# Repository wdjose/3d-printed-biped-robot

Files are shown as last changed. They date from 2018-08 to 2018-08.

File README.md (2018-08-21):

# 3D-Printed Biped Robot
This repository contains the 3D model and the source code for the 3D-printed biped robot presented in the conference: 

> [W. J. D. Jose and M. C. Ramos, "Development of a 3D-printed biped robot with distributed joint control," 2018 4th International Conference on Control, Automation and Robotics (ICCAR), Auckland, 2018, pp. 71-75.](https://ieeexplore.ieee.org/document/8384647/ "Development of a 3D-printed biped robot with distributed joint control")

The biped robot was designed from scratch: all mechanical, electronic, and control designs were built by the authors. 

Below are descriptions of the directories in the repository: 
1. 3D Model: This contains the SolidWorks parts and assemblies which was 3D-printed and laser cut. 
2. PCB Schematic and Layout: This contains EAGLE schematic and layout files for both the master and joint controllers. 
3. Joint Controller: This is the MPLAB X project used for motor control for the joint controller. 
4. Master Controller: This is the MPLAB X project used for motion control of the biped for the master controller. 

Additional details can be provided upon request. 

This project was developed at Electrical and Electronics Engineering Institute, University of the Philippines Diliman.

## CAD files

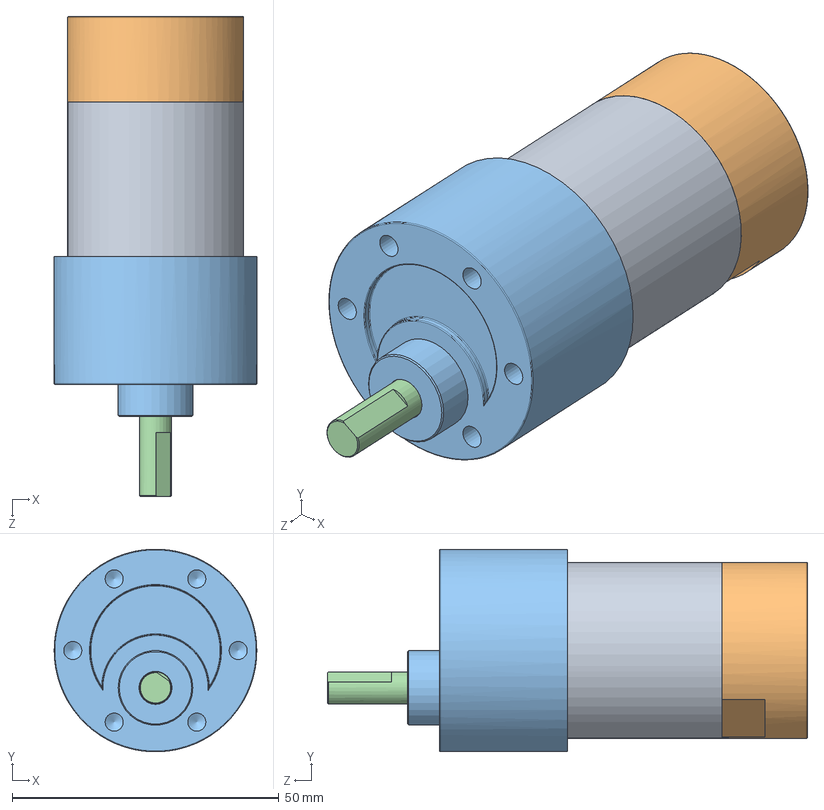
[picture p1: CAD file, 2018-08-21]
3D Model/Motor.SLDASM
38.0 x 38.0 x 90.0 mm
Motor Proper
Motor Encoder
Motor Gearbox
Motor Shaft

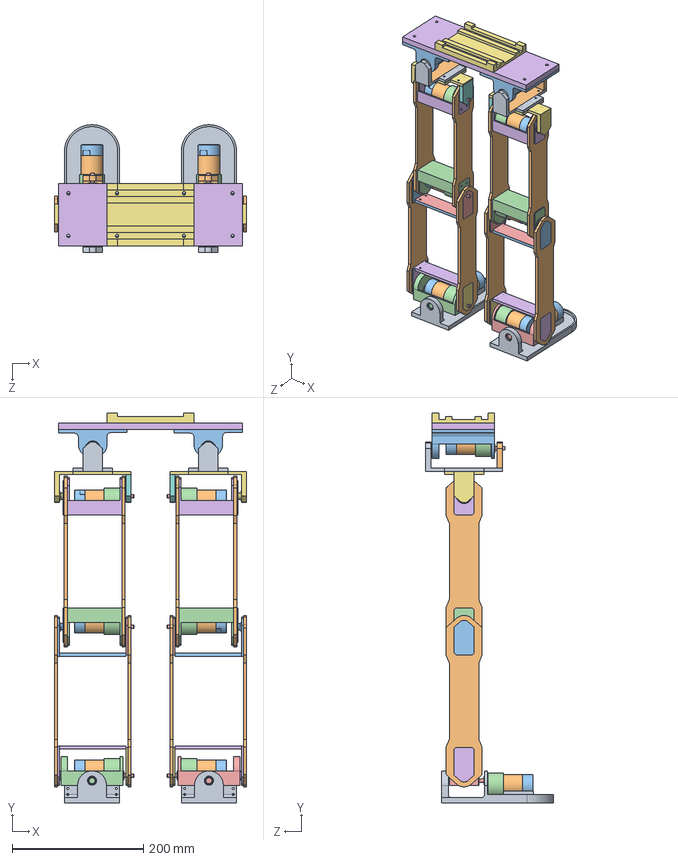
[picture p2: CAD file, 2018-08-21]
3D Model/Biped.SLDASM
293.0 x 593.9 x 194.5 mm
Foot x 2
Motor Proper x 10
Motor Encoder x 10
Motor Gearbox x 10
Motor Shaft x 10
Ankle Bearing x 2
Ankle DShaft x 2
Bearing Inner x 10
Bearing Outer x 10
Thigh and Shin x 8
Knee Bearing x 2
Knee x 2
Knee DShaft x 2
Hip A x 2
Hip Bearing A x 2
Hip DShaft A x 2
Hip Bearing B x 2
Hip DShaft B x 2
Hip B x 2
Ankle Left
Ankle Right
Torso Base
Torso Base Reinforcement

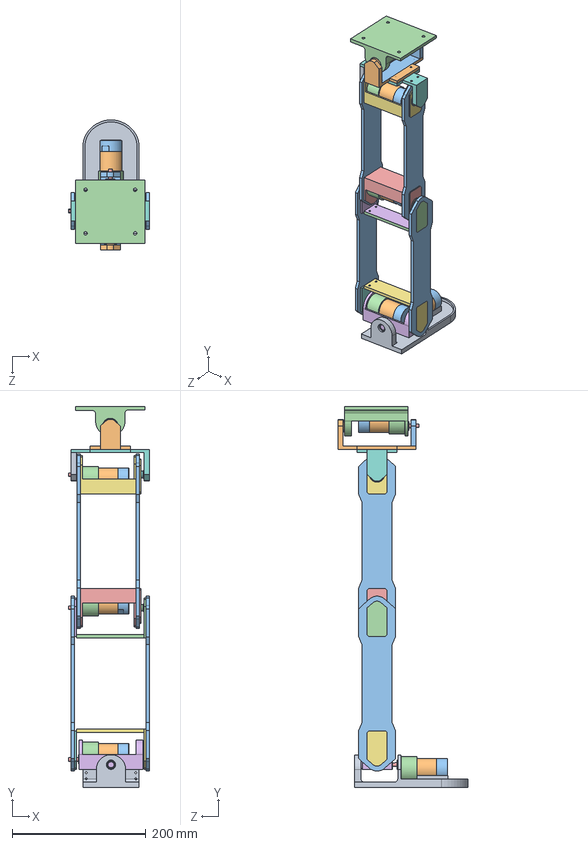
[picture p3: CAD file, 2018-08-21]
3D Model/Leg Right.SLDASM
121.0 x 568.9 x 194.5 mm
Foot
Motor Proper x 5
Motor Encoder x 5
Motor Gearbox x 5
Motor Shaft x 5
Ankle Right
Ankle Bearing
Ankle DShaft
Bearing Inner x 5
Bearing Outer x 5
Thigh and Shin x 4
Knee Bearing
Knee
Knee DShaft
Hip A
Hip Bearing A
Hip DShaft A
Hip Bearing B
Hip DShaft B
Hip B

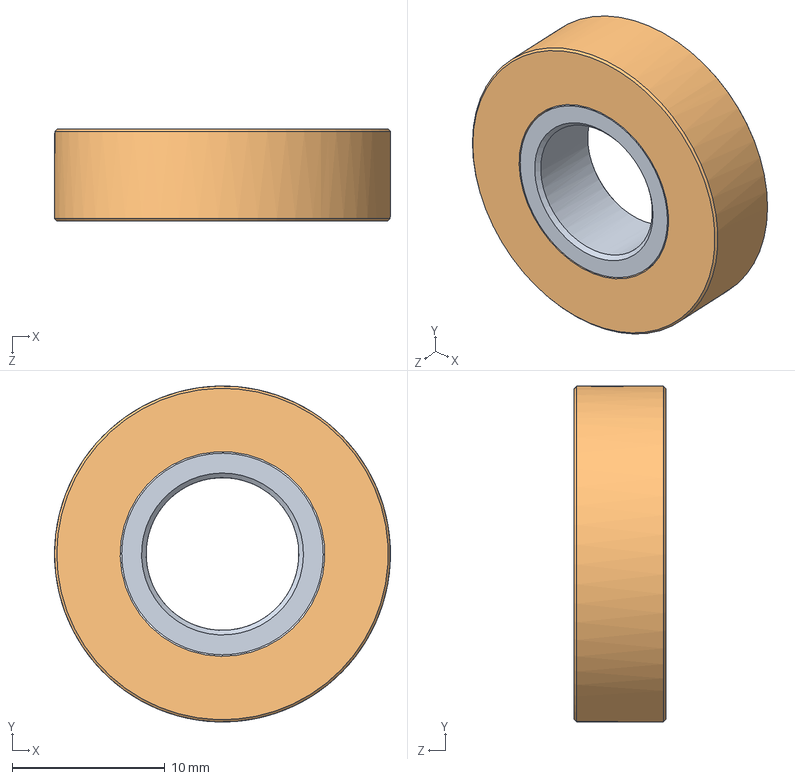
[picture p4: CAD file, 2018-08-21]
3D Model/Bearing.SLDASM
22.0 x 22.0 x 6.00 mm
Bearing Inner
Bearing Outer

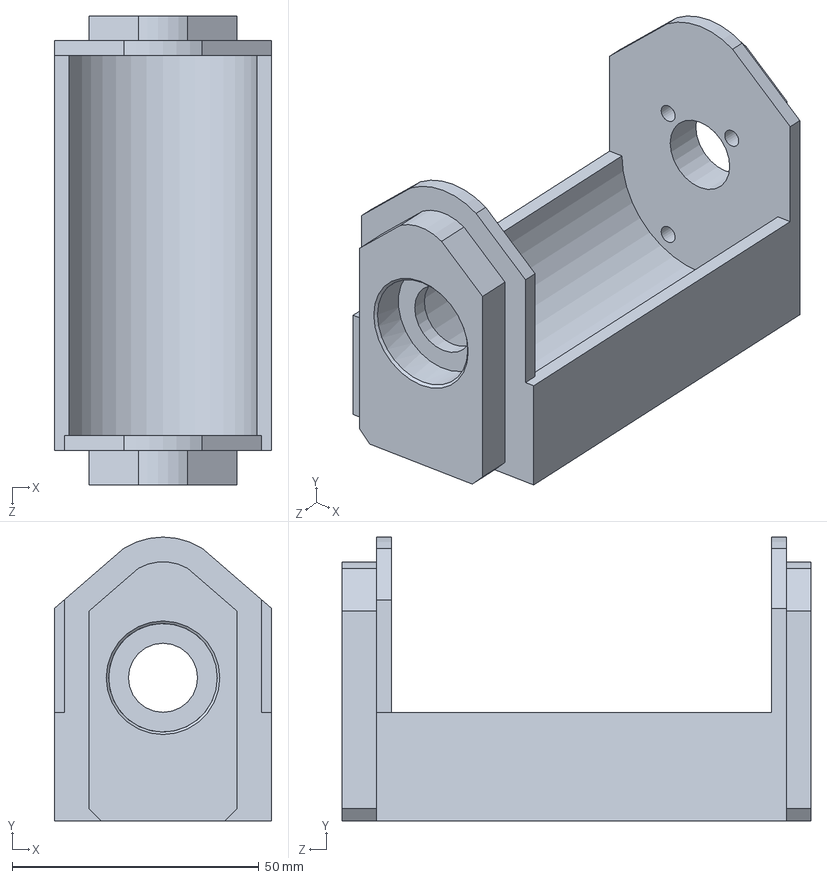
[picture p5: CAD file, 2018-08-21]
3D Model/Hip A.SLDPRT
44.0 x 57.5 x 95.0 mm

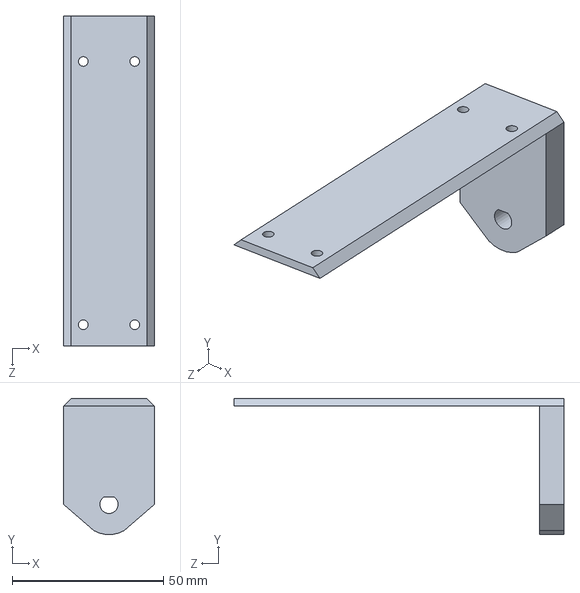
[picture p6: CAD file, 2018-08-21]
3D Model/Hip DShaft A.SLDPRT
30.0 x 44.9 x 109.0 mm

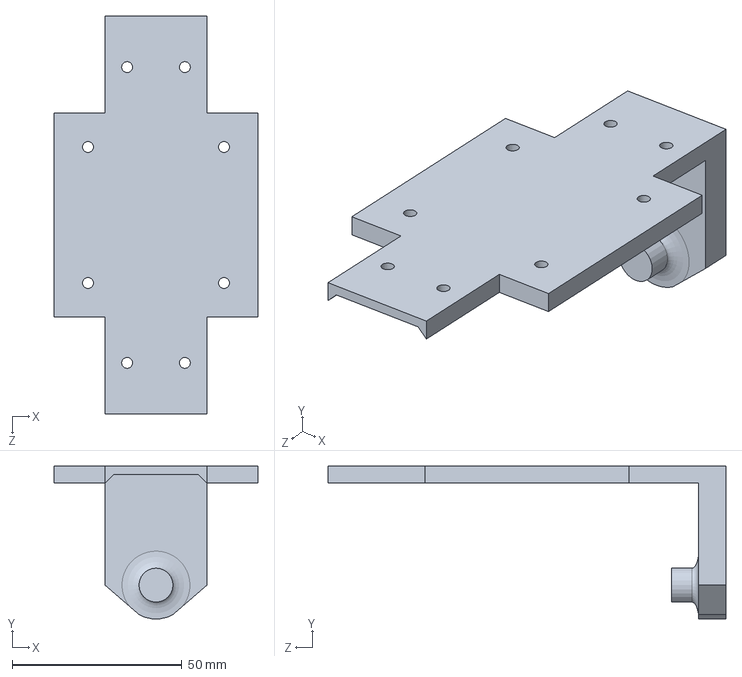
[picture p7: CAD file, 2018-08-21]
3D Model/Hip Bearing B.SLDPRT
60.0 x 44.9 x 117.0 mm

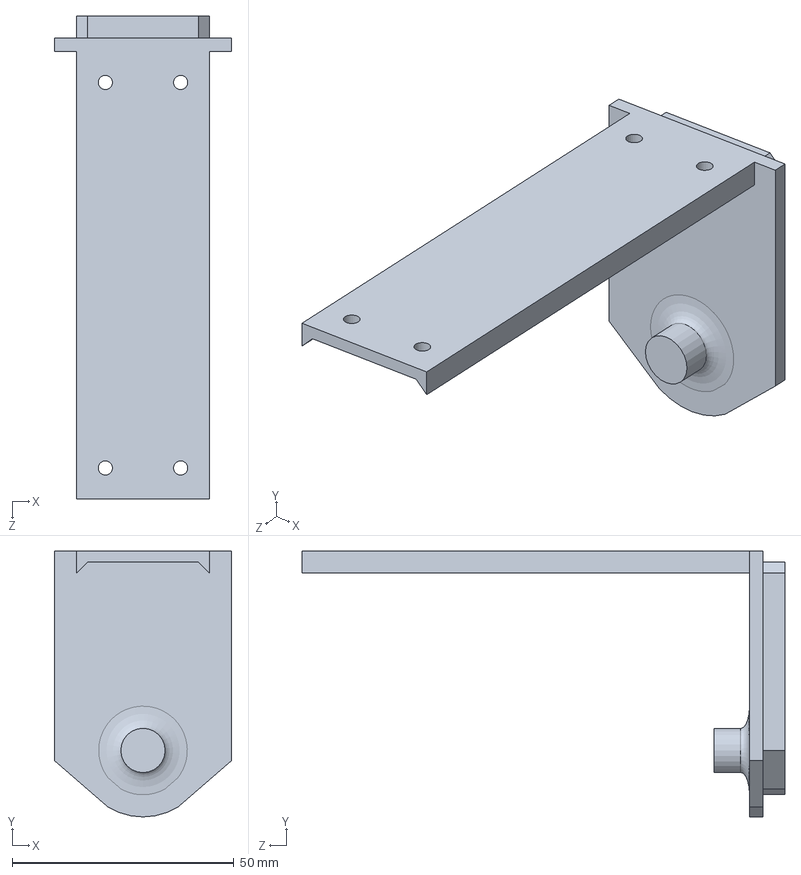
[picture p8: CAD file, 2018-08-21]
3D Model/Knee Bearing.SLDPRT
40.0 x 60.0 x 109.0 mm

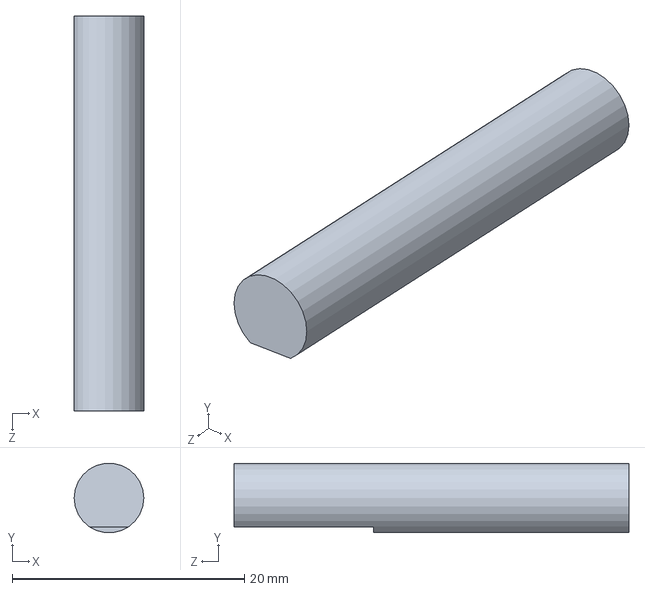
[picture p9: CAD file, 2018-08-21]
3D Model/Motor Shaft.SLDPRT
6.00 x 5.96 x 34.0 mm

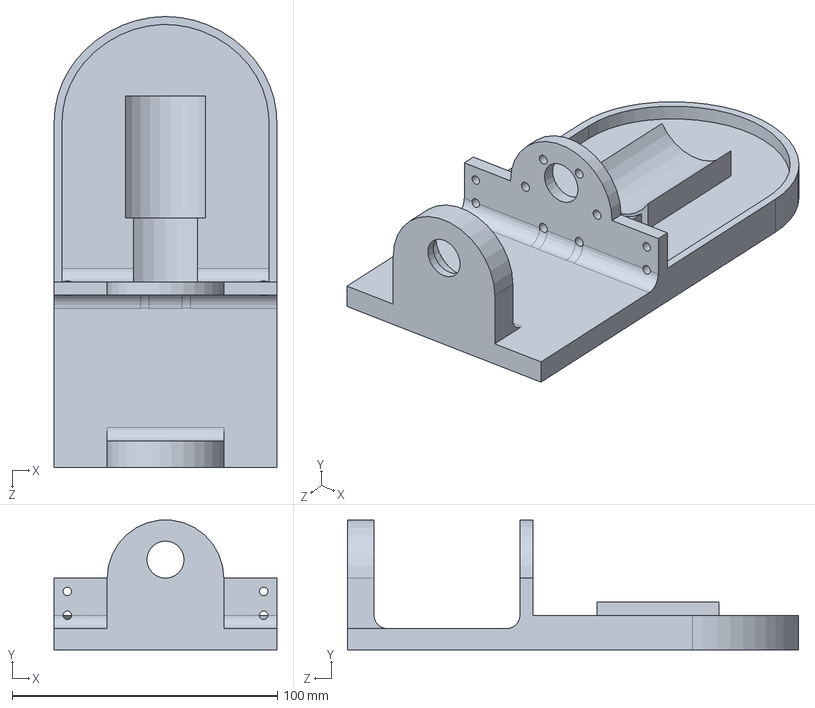
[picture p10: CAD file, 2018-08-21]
3D Model/Foot.SLDPRT
84.0 x 48.9 x 170.0 mm

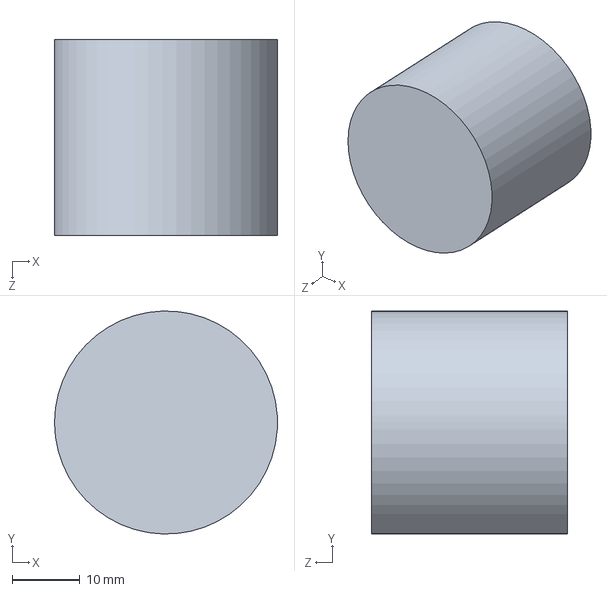
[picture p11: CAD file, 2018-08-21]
3D Model/Motor Proper.SLDPRT
33.0 x 33.0 x 29.0 mm

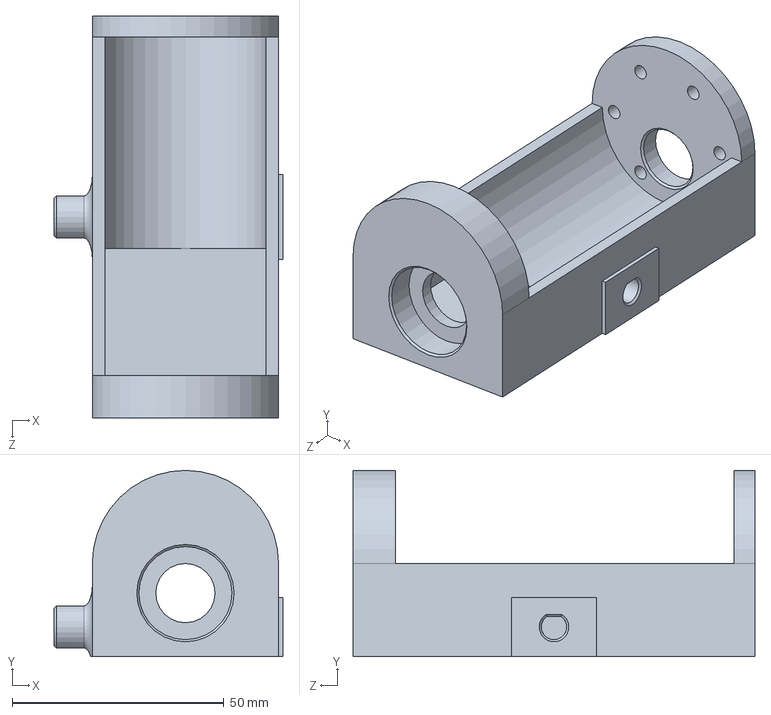
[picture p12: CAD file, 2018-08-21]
3D Model/Ankle Right.SLDPRT
54.0 x 44.0 x 95.0 mm

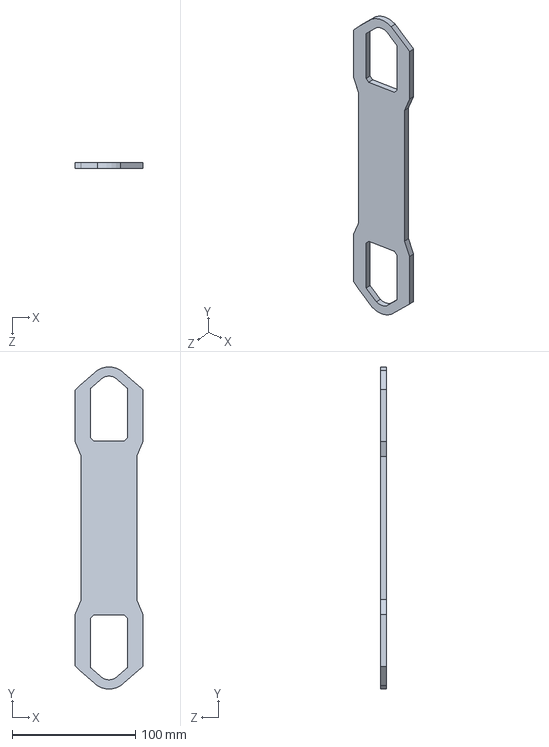
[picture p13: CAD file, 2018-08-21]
3D Model/Thigh and Shin.SLDPRT
55.0 x 261.0 x 5.00 mm

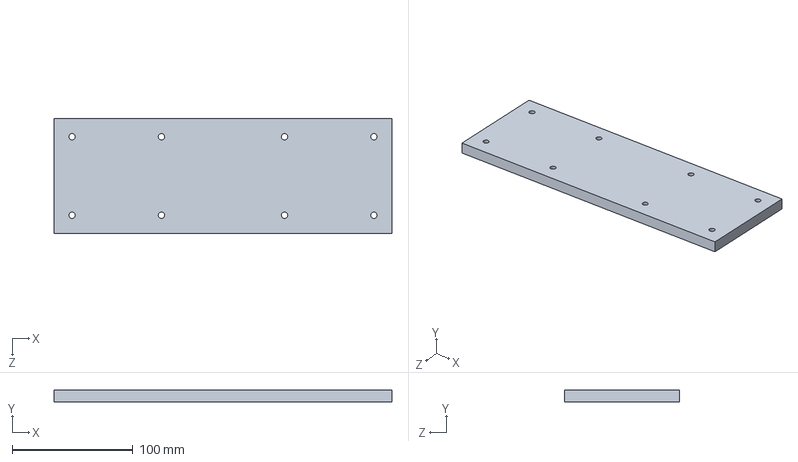
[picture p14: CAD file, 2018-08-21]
3D Model/Torso Base.SLDPRT
280.0 x 10.0 x 95.0 mm

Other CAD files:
3D Model/Leg Left.SLDASM
3D Model/Knee.SLDPRT
3D Model/Hip DShaft B.SLDPRT
3D Model/Bearing Outer.SLDPRT
3D Model/Ankle Bearing.SLDPRT
3D Model/Ankle DShaft.SLDPRT
3D Model/Ankle Left.SLDPRT
3D Model/Bearing Inner.SLDPRT
3D Model/Hip B.SLDPRT
3D Model/Hip Bearing A.SLDPRT
3D Model/Knee DShaft.SLDPRT
3D Model/Motor Encoder.SLDPRT
3D Model/Motor Gearbox.SLDPRT
3D Model/Torso Base Reinforcement.SLDPRT

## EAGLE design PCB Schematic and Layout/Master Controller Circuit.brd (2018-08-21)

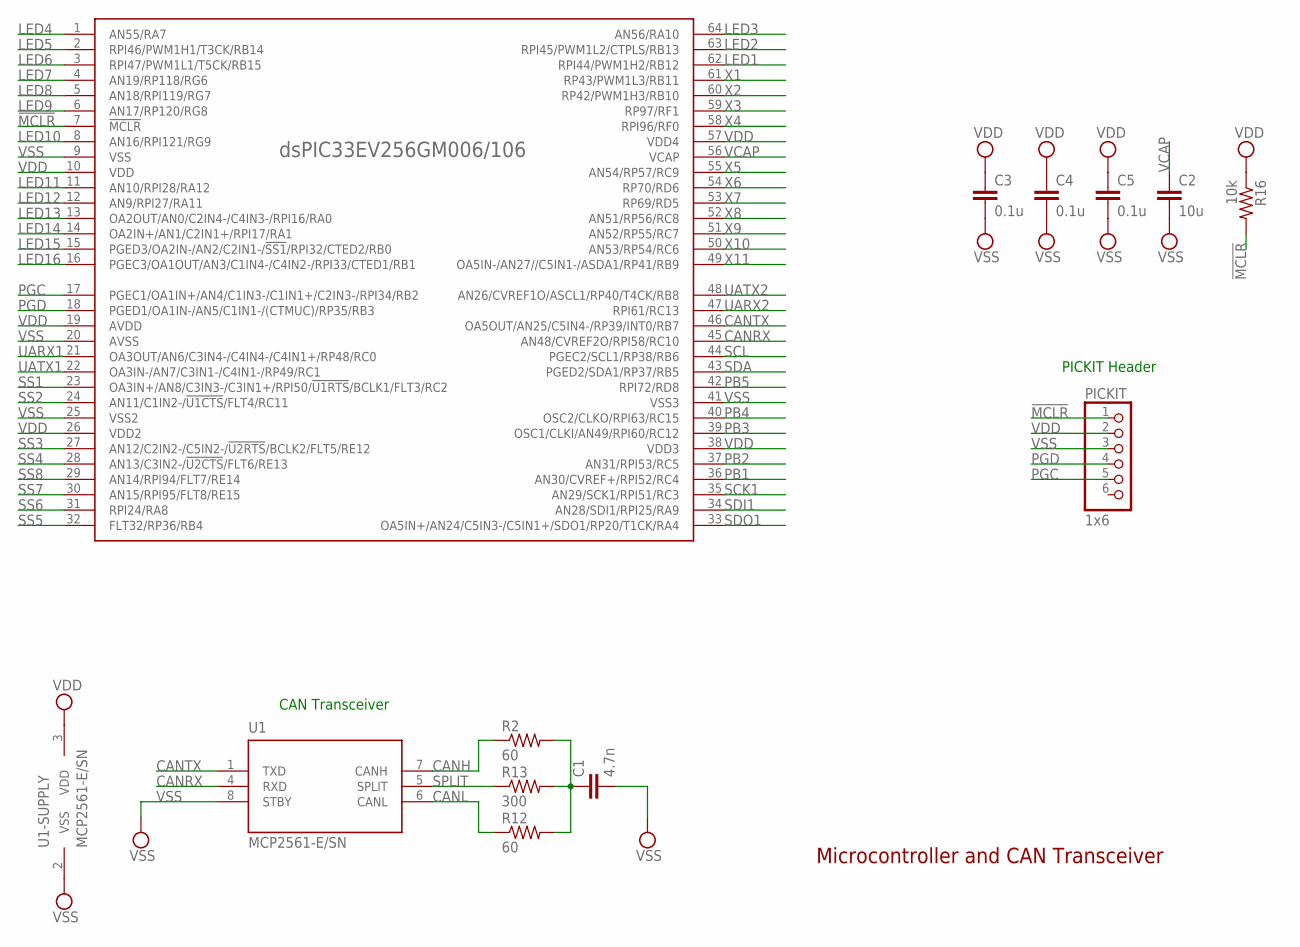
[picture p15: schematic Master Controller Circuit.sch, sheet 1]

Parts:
C1: 4.7n; C0805
C2: 10u; C0805
C3, C4, C5: 0.1u; C0805
PICKIT: 1x6; 1X06
R2, R12: 60; R0805
R13: 300; R0805
R16: 10k; R0805
U1: MCP2561-E/SN; SOIC-8
U$1: DSPIC33EV256GM106; TQFP64-10X10

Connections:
!MCLR: PICKIT.1, R16.2, U$1.7 (!MCLR); also elsewhere on the board
CANH: R2.1, U1.7 (CANH); also elsewhere on the board
CANL: R12.1, U1.6 (CANL); also elsewhere on the board
CANRX: U1.4 (RXD), U$1.45 (AN48/CVREF2O/RPI58/RC10)
CANTX: U1.1 (TXD), U$1.46 (OA5OUT/AN25/C5IN4-/RP39/INT0/RB7)
LED1: U$1.62 (RPI44/PWM1H2/RB12); also elsewhere on the board
LED2: U$1.63 (RPI45/PWM1L2/CTPLS/RB13); also elsewhere on the board
LED3: U$1.64 (AN56/RA10); also elsewhere on the board
LED4: U$1.1 (AN55/RA7); also elsewhere on the board
LED5: U$1.2 (RPI46/PWM1H1/T3CK/RB14); also elsewhere on the board
LED6: U$1.3 (RPI47/PWM1L1/T5CK/RB15); also elsewhere on the board
LED7: U$1.4 (AN19/RP118/RG6); also elsewhere on the board
LED8: U$1.5 (AN18/RPI119/RG7); also elsewhere on the board
LED9: U$1.6 (AN17/RP120/RG8); also elsewhere on the board
LED10: U$1.8 (AN16/RPI121/RG9); also elsewhere on the board
LED11: U$1.11 (AN10/RPI28/RA12); also elsewhere on the board
LED12: U$1.12 (AN9/RPI27/RA11); also elsewhere on the board
LED13: U$1.13 (OA2OUT/AN0/C2IN4-/C4IN3-/RPI16/RA0); also elsewhere on the board
LED14: U$1.14 (OA2IN+/AN1/C2IN1+/RPI17/RA1); also elsewhere on the board
LED15: U$1.15 (PGED3/OA2IN-/AN2/C2IN1-/!SS1!/RPI32/CTE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); also elsewhere on the board
LED16: U$1.16 (PGEC3/OA1OUT/AN3/C1IN4-/C4IN2-/RPI33/CT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); also elsewhere on the board
unnamed: C1.1, R2.2, R12.2, R13.2
PB1: U$1.36 (AN30/CVREF+/RPI52/RC4); also elsewhere on the board
PB2: U$1.37 (AN31/RPI53/RC5); also elsewhere on the board
PB3: U$1.39 (OSC1/CLKI/AN49/RPI60/RC12); also elsewhere on the board
PB4: U$1.40 (OSC2/CLKO/RPI63/RC15); also elsewhere on the board
PB5: U$1.42 (RPI72/RD8); also elsewhere on the board
PGC: PICKIT.5, U$1.17 (PGEC1/OA1IN+/AN4/C1IN3-/C1IN1+/C2IN3-/R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)
PGD: PICKIT.4, U$1.18 (PGED1/OA1IN-/AN5/C1IN1-/(CTMUC)/RP35/RB3)
SCK1: U$1.35 (AN29/SCK1/RPI51/RC3); also elsewhere on the board
SCL: U$1.44 (PGEC2/SCL1/RP38/RB6); also elsewhere on the board
SDA: U$1.43 (PGED2/SDA1/RP37/RB5); also elsewhere on the board
SDI1: U$1.34 (AN28/SDI1/RPI25/RA9); also elsewhere on the board
SDO1: U$1.33 (OA5IN+/AN24/C5IN3-/C5IN1+/SDO1/RP20/T1C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); also elsewhere on the board
SPLIT: R13.1, U1.5 (SPLIT)
SS1: U$1.23 (OA3IN+/AN8/C3IN3-/C3IN1+/RPI50/!U1RTS!/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); also elsewhere on the board
SS2: U$1.24 (AN11/C1IN2-/!U1CTS!/FLT4/RC11); also elsewhere on the board
SS3: U$1.27 (AN12/C2IN2-/C5IN2-/!U2RTS!/BCLK2/FLT5/R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); also elsewhere on the board
SS4: U$1.28 (AN13/C3IN2-/!U2CTS!/FLT6/RE13); also elsewhere on the board
SS5: U$1.32 (FLT32/RP36/RB4); also elsewhere on the board
SS6: U$1.31 (RPI24/RA8); also elsewhere on the board
SS7: U$1.30 (AN15/RPI95/FLT8/RE15); also elsewhere on the board
SS8: U$1.29 (AN14/RPI94/FLT7/RE14); also elsewhere on the board
UARX1: U$1.21 (OA3OUT/AN6/C3IN4-/C4IN4-/C4IN1+/RP48/RC0); also elsewhere on the board
UARX2: U$1.47 (RPI61/RC13); also elsewhere on the board
UATX1: U$1.22 (OA3IN-/AN7/C3IN1-/C4IN1-/RP49/RC1); also elsewhere on the board
UATX2: U$1.48 (AN26/CVREF1O/ASCL1/RP40/T4CK/RB8); also elsewhere on the board
VCAP: C2.1, U$1.56 (VCAP)
VDD: C3.1, C4.1, C5.1, PICKIT.2, R16.1, U1.3 (VDD), U$1.10 (VDD), U$1.19 (AVDD), U$1.26 (VDD2), U$1.38 (VDD3), U$1.57 (VDD4); also elsewhere on the board
VSS: C1.2, C2.2, C3.2, C4.2, C5.2, PICKIT.3, U1.2 (VSS), U1.8 (STBY), U$1.9 (VSS), U$1.20 (AVSS), U$1.25 (VSS2), U$1.41 (VSS3); also elsewhere on the board
X1: U$1.61 (RP43/PWM1L3/RB11); also elsewhere on the board
X2: U$1.60 (RP42/PWM1H3/RB10); also elsewhere on the board
X3: U$1.59 (RP97/RF1); also elsewhere on the board
X4: U$1.58 (RPI96/RF0); also elsewhere on the board
X5: U$1.55 (AN54/RP57/RC9); also elsewhere on the board
X6: U$1.54 (RP70/RD6); also elsewhere on the board
X7: U$1.53 (RP69/RD5); also elsewhere on the board
X8: U$1.52 (AN51/RP56/RC8); also elsewhere on the board
X9: U$1.51 (AN52/RP55/RC7); also elsewhere on the board
X10: U$1.50 (AN53/RP54/RC6); also elsewhere on the board
X11: U$1.49 (OA5IN-/AN27//C5IN1-/ASDA1/RP41/RB9); also elsewhere on the board

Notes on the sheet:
PICKIT Header
CAN Transceiver
Microcontroller and CAN Transceiver

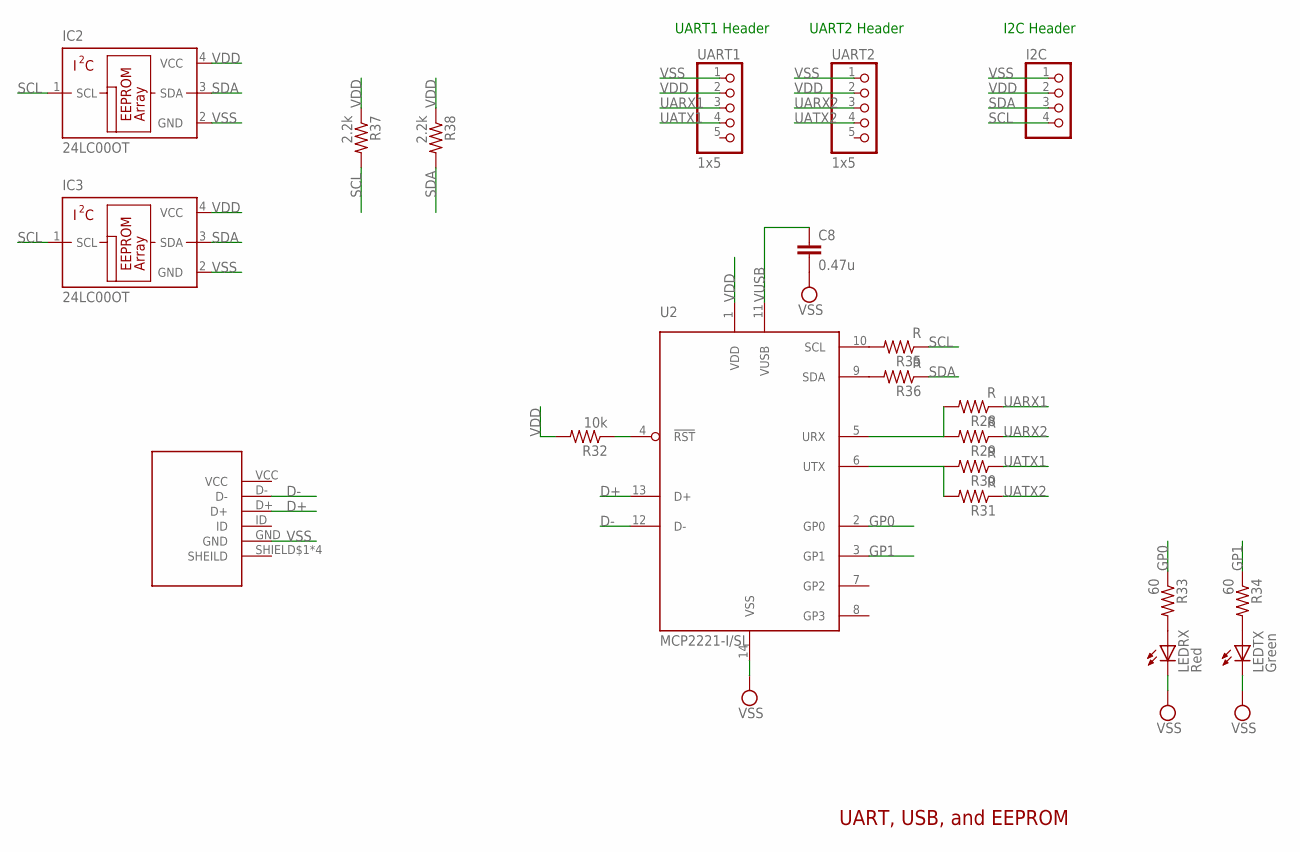
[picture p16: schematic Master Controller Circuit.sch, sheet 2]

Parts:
C8: 0.47u; C0805
I2C: PINHD-1X4; 1X04
IC2, IC3: 24LC00OT; SOT23-5L
J1: 10118193-0001LF
LEDRX: Red; CHIP-LED0805
LEDTX: Green; CHIP-LED0805
R28, R29, R30, R31, R35, R36: R; R0805
R32: 10k; R0805
R33, R34: 60; R0805
R37, R38: 2.2k; R0805
U2: MCP2221-I/SL; SOIC14
UART1, UART2: 1x5; 1X05

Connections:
D+: J1.D+, U2.13 (D+)
D-: J1.D-, U2.12 (D-)
GP0: R33.1, U2.2 (GP0)
GP1: R34.1, U2.3 (GP1)
unnamed: R28.2, R29.2, U2.5 (URX)
unnamed: R30.2, R31.2, U2.6 (UTX)
unnamed: R35.2, U2.10 (SCL)
unnamed: R36.2, U2.9 (SDA)
unnamed: R32.1, U2.4 (!RST)
unnamed: LEDRX.A, R33.2
unnamed: LEDTX.A, R34.2
SCL: I2C.4, IC2.1 (SCL), IC3.1 (SCL), R35.1, R37.2; also elsewhere on the board
SDA: I2C.3, IC2.3 (SDA), IC3.3 (SDA), R36.1, R38.2; also elsewhere on the board
UARX1: R28.1, UART1.3; also elsewhere on the board
UARX2: R29.1, UART2.3; also elsewhere on the board
UATX1: R30.1, UART1.4; also elsewhere on the board
UATX2: R31.1, UART2.4; also elsewhere on the board
VDD: I2C.2, IC2.4 (VCC), IC3.4 (VCC), R32.2, R37.1, R38.1, U2.1 (VDD), UART1.2, UART2.2; also elsewhere on the board
VSS: C8.2, I2C.1, IC2.2 (GND), IC3.2 (GND), J1.GND, LEDRX.C, LEDTX.C, U2.14 (VSS), UART1.1, UART2.1; also elsewhere on the board
VUSB: C8.1, U2.11 (VUSB)

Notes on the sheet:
UART, USB, and EEPROM
UART1 Header
UART2 Header
I2C Header

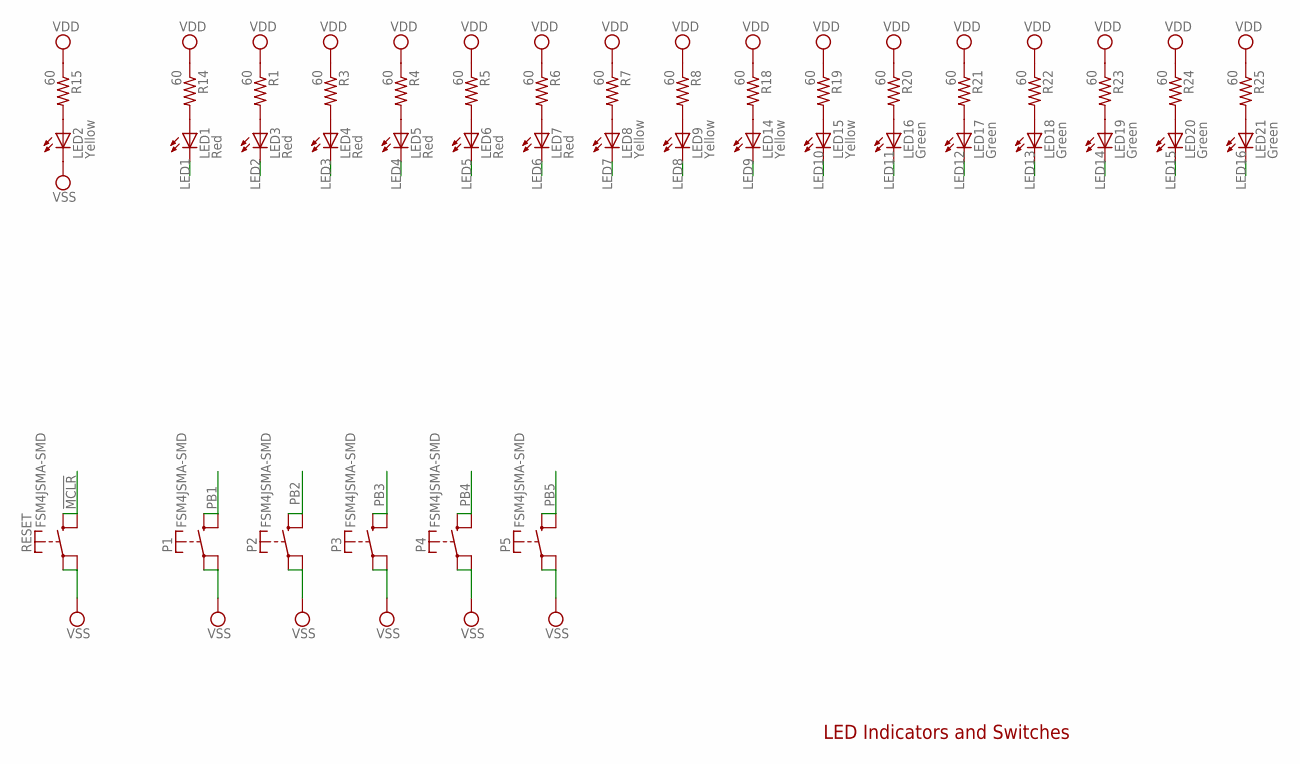
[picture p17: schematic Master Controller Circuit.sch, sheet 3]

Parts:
LED1, LED3, LED4, LED5, LED6, LED7: Red; CHIP-LED0805
LED2, LED8, LED9, LED14, LED15: Yellow; CHIP-LED0805
LED16, LED17, LED18, LED19, LED20, LED21: Green; CHIP-LED0805
P1, P2, P3, P4, P5: FSM4JSMA-SMD
R1, R3, R4, R5, R6, R7, R8, R14, R15, R18, R19, R20, R21, R22, R23, R24, R25: 60; R0805
RESET: FSM4JSMA-SMD

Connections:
!MCLR: RESET.P$3 (S), RESET.P$4 (S); also elsewhere on the board
LED1: LED1.C; also elsewhere on the board
LED2: LED3.C; also elsewhere on the board
LED3: LED4.C; also elsewhere on the board
LED4: LED5.C; also elsewhere on the board
LED5: LED6.C; also elsewhere on the board
LED6: LED7.C; also elsewhere on the board
LED7: LED8.C; also elsewhere on the board
LED8: LED9.C; also elsewhere on the board
LED9: LED14.C; also elsewhere on the board
LED10: LED15.C; also elsewhere on the board
LED11: LED16.C; also elsewhere on the board
LED12: LED17.C; also elsewhere on the board
LED13: LED18.C; also elsewhere on the board
LED14: LED19.C; also elsewhere on the board
LED15: LED20.C; also elsewhere on the board
LED16: LED21.C; also elsewhere on the board
unnamed: LED1.A, R14.2
unnamed: LED2.A, R15.2
unnamed: LED3.A, R1.2
unnamed: LED4.A, R3.2
unnamed: LED5.A, R4.2
unnamed: LED6.A, R5.2
unnamed: LED7.A, R6.2
unnamed: LED8.A, R7.2
unnamed: LED9.A, R8.2
unnamed: LED14.A, R18.2
unnamed: LED15.A, R19.2
unnamed: LED16.A, R20.2
unnamed: LED17.A, R21.2
unnamed: LED18.A, R22.2
unnamed: LED19.A, R23.2
unnamed: LED20.A, R24.2
unnamed: LED21.A, R25.2
PB1: P1.P$3 (S), P1.P$4 (S); also elsewhere on the board
PB2: P2.P$3 (S), P2.P$4 (S); also elsewhere on the board
PB3: P3.P$3 (S), P3.P$4 (S); also elsewhere on the board
PB4: P4.P$3 (S), P4.P$4 (S); also elsewhere on the board
PB5: P5.P$3 (S), P5.P$4 (S); also elsewhere on the board
VDD: R1.1, R3.1, R4.1, R5.1, R6.1, R7.1, R8.1, R14.1, R15.1, R18.1, R19.1, R20.1, R21.1, R22.1, R23.1, R24.1, R25.1; also elsewhere on the board
VSS: LED2.C, P1.P$1, P1.P$2, P2.P$1, P2.P$2, P3.P$1, P3.P$2, P4.P$1, P4.P$2, P5.P$1, P5.P$2, RESET.P$1, RESET.P$2; also elsewhere on the board

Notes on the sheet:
LED Indicators and Switches

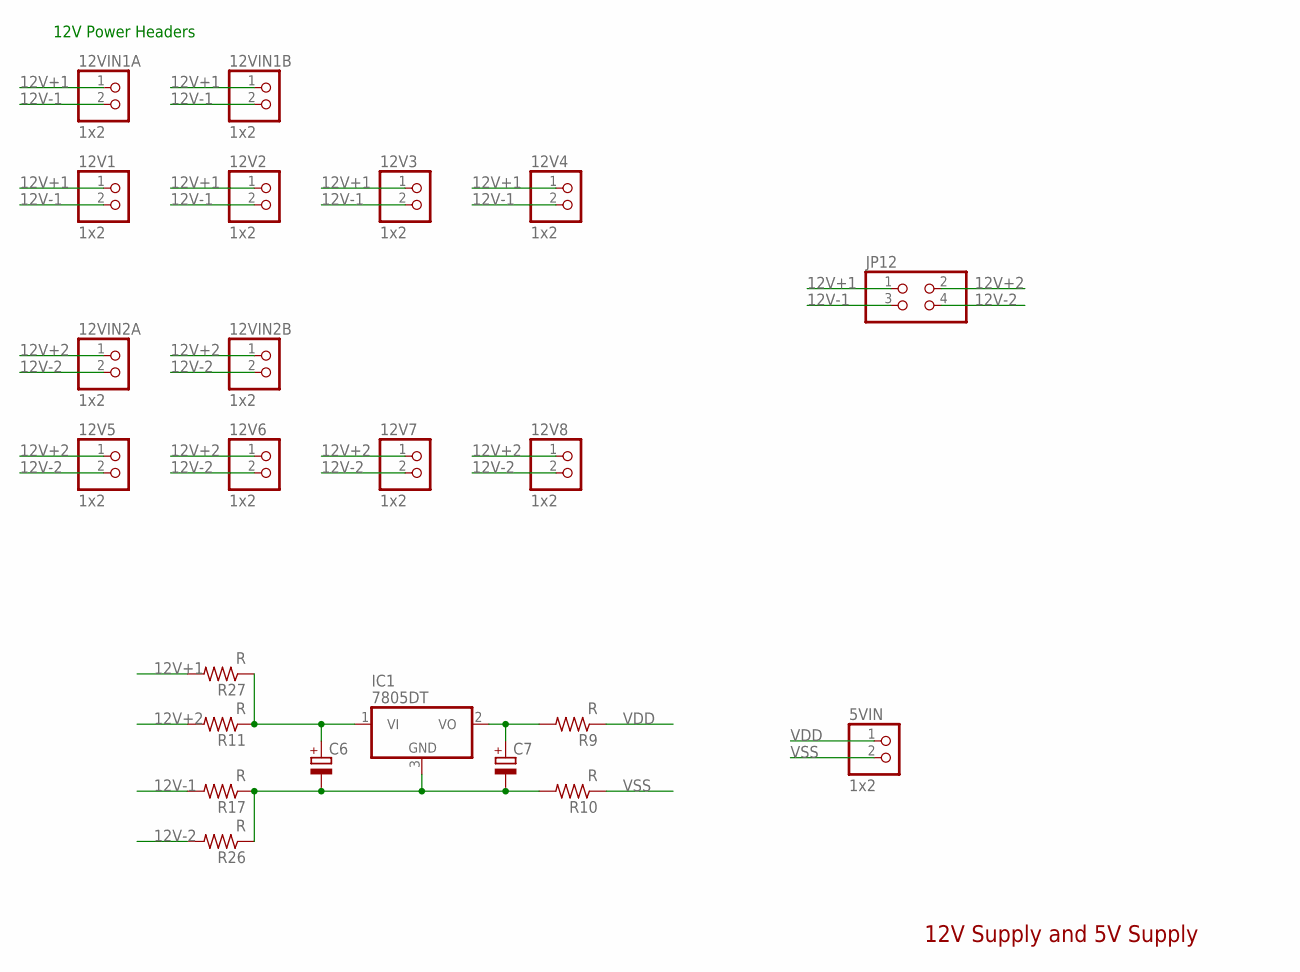
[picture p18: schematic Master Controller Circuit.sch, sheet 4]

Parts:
5VIN, 12V1, 12V2, 12V3, 12V4, 12V5, 12V6, 12V7, 12V8, 12VIN1A, 12VIN1B, 12VIN2A, 12VIN2B: 1x2; 1X02
C6, C7: CPOL-EU153CLV-0605; 153CLV-0605
IC1: 7805DT; TO252
JP12: PINHD-2X2; 2X02
R9, R10, R11, R17, R26, R27: R; R0805

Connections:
12V+1: 12V1.1, 12V2.1, 12V3.1, 12V4.1, 12VIN1A.1, 12VIN1B.1, JP12.1, R27.2
12V+2: 12V5.1, 12V6.1, 12V7.1, 12V8.1, 12VIN2A.1, 12VIN2B.1, JP12.2, R11.2
12V-1: 12V1.2, 12V2.2, 12V3.2, 12V4.2, 12VIN1A.2, 12VIN1B.2, JP12.3, R17.2
12V-2: 12V5.2, 12V6.2, 12V7.2, 12V8.2, 12VIN2A.2, 12VIN2B.2, JP12.4, R26.2
unnamed: C7.+, IC1.2 (VO), R9.2
unnamed: C6.-, C7.-, IC1.3 (GND), R10.2, R17.1, R26.1
unnamed: C6.+, IC1.1 (VI), R11.1, R27.1
VDD: 5VIN.1, R9.1; also elsewhere on the board
VSS: 5VIN.2, R10.1; also elsewhere on the board

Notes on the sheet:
12V Supply and 5V Supply
12V Power Headers

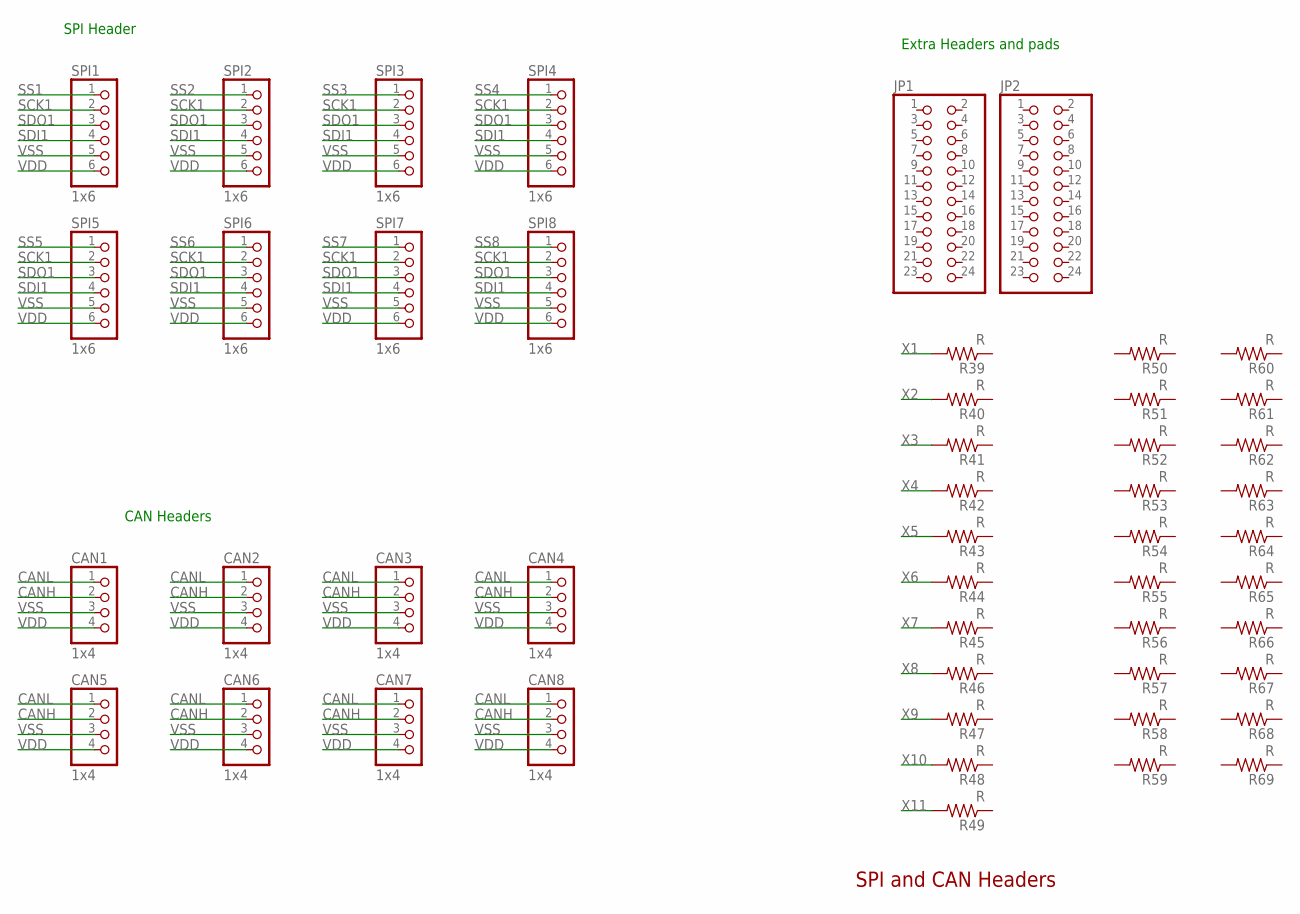
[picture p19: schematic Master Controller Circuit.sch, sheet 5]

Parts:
CAN1, CAN2, CAN3, CAN4, CAN5, CAN6, CAN7, CAN8: 1x4; 1X04
JP1, JP2: PINHD-2X12; 2X12
R39, R40, R41, R42, R43, R44, R45, R46, R47, R48, R49, R50, R51, R52, R53, R54, R55, R56, R57, R58, R59, R60, R61, R62, R63, R64, R65, R66, R67, R68, R69: R; R0603
SPI1, SPI2, SPI3, SPI4, SPI5, SPI6, SPI7, SPI8: 1x6; 1X06

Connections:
CANH: CAN1.2, CAN2.2, CAN3.2, CAN4.2, CAN5.2, CAN6.2, CAN7.2, CAN8.2; also elsewhere on the board
CANL: CAN1.1, CAN2.1, CAN3.1, CAN4.1, CAN5.1, CAN6.1, CAN7.1, CAN8.1; also elsewhere on the board
SCK1: SPI1.2, SPI2.2, SPI3.2, SPI4.2, SPI5.2, SPI6.2, SPI7.2, SPI8.2; also elsewhere on the board
SDI1: SPI1.4, SPI2.4, SPI3.4, SPI4.4, SPI5.4, SPI6.4, SPI7.4, SPI8.4; also elsewhere on the board
SDO1: SPI1.3, SPI2.3, SPI3.3, SPI4.3, SPI5.3, SPI6.3, SPI7.3, SPI8.3; also elsewhere on the board
SS1: SPI1.1; also elsewhere on the board
SS2: SPI2.1; also elsewhere on the board
SS3: SPI3.1; also elsewhere on the board
SS4: SPI4.1; also elsewhere on the board
SS5: SPI5.1; also elsewhere on the board
SS6: SPI6.1; also elsewhere on the board
SS7: SPI7.1; also elsewhere on the board
SS8: SPI8.1; also elsewhere on the board
VDD: CAN1.4, CAN2.4, CAN3.4, CAN4.4, CAN5.4, CAN6.4, CAN7.4, CAN8.4, SPI1.6, SPI2.6, SPI3.6, SPI4.6, SPI5.6, SPI6.6, SPI7.6, SPI8.6; also elsewhere on the board
VSS: CAN1.3, CAN2.3, CAN3.3, CAN4.3, CAN5.3, CAN6.3, CAN7.3, CAN8.3, SPI1.5, SPI2.5, SPI3.5, SPI4.5, SPI5.5, SPI6.5, SPI7.5, SPI8.5; also elsewhere on the board
X1: R39.2; also elsewhere on the board
X2: R40.2; also elsewhere on the board
X3: R41.2; also elsewhere on the board
X4: R42.2; also elsewhere on the board
X5: R43.2; also elsewhere on the board
X6: R44.2; also elsewhere on the board
X7: R45.2; also elsewhere on the board
X8: R46.2; also elsewhere on the board
X9: R47.2; also elsewhere on the board
X10: R48.2; also elsewhere on the board
X11: R49.2; also elsewhere on the board

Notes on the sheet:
SPI and CAN Headers
SPI Header
CAN Headers
Extra Headers and pads

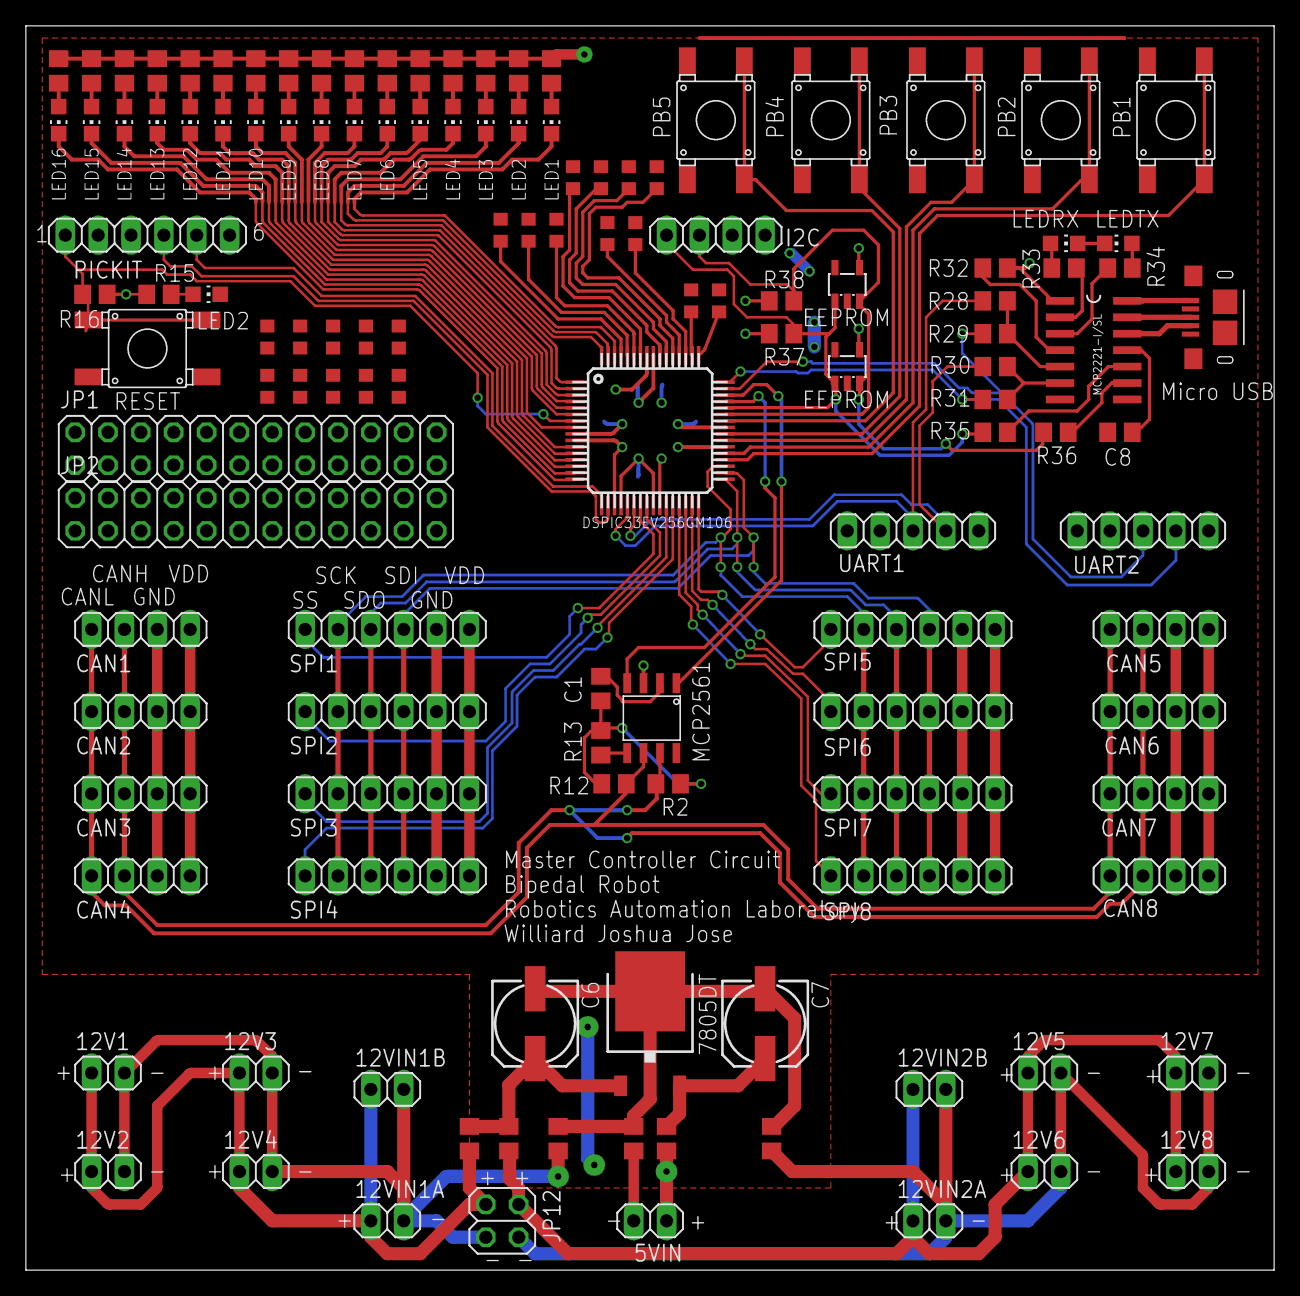
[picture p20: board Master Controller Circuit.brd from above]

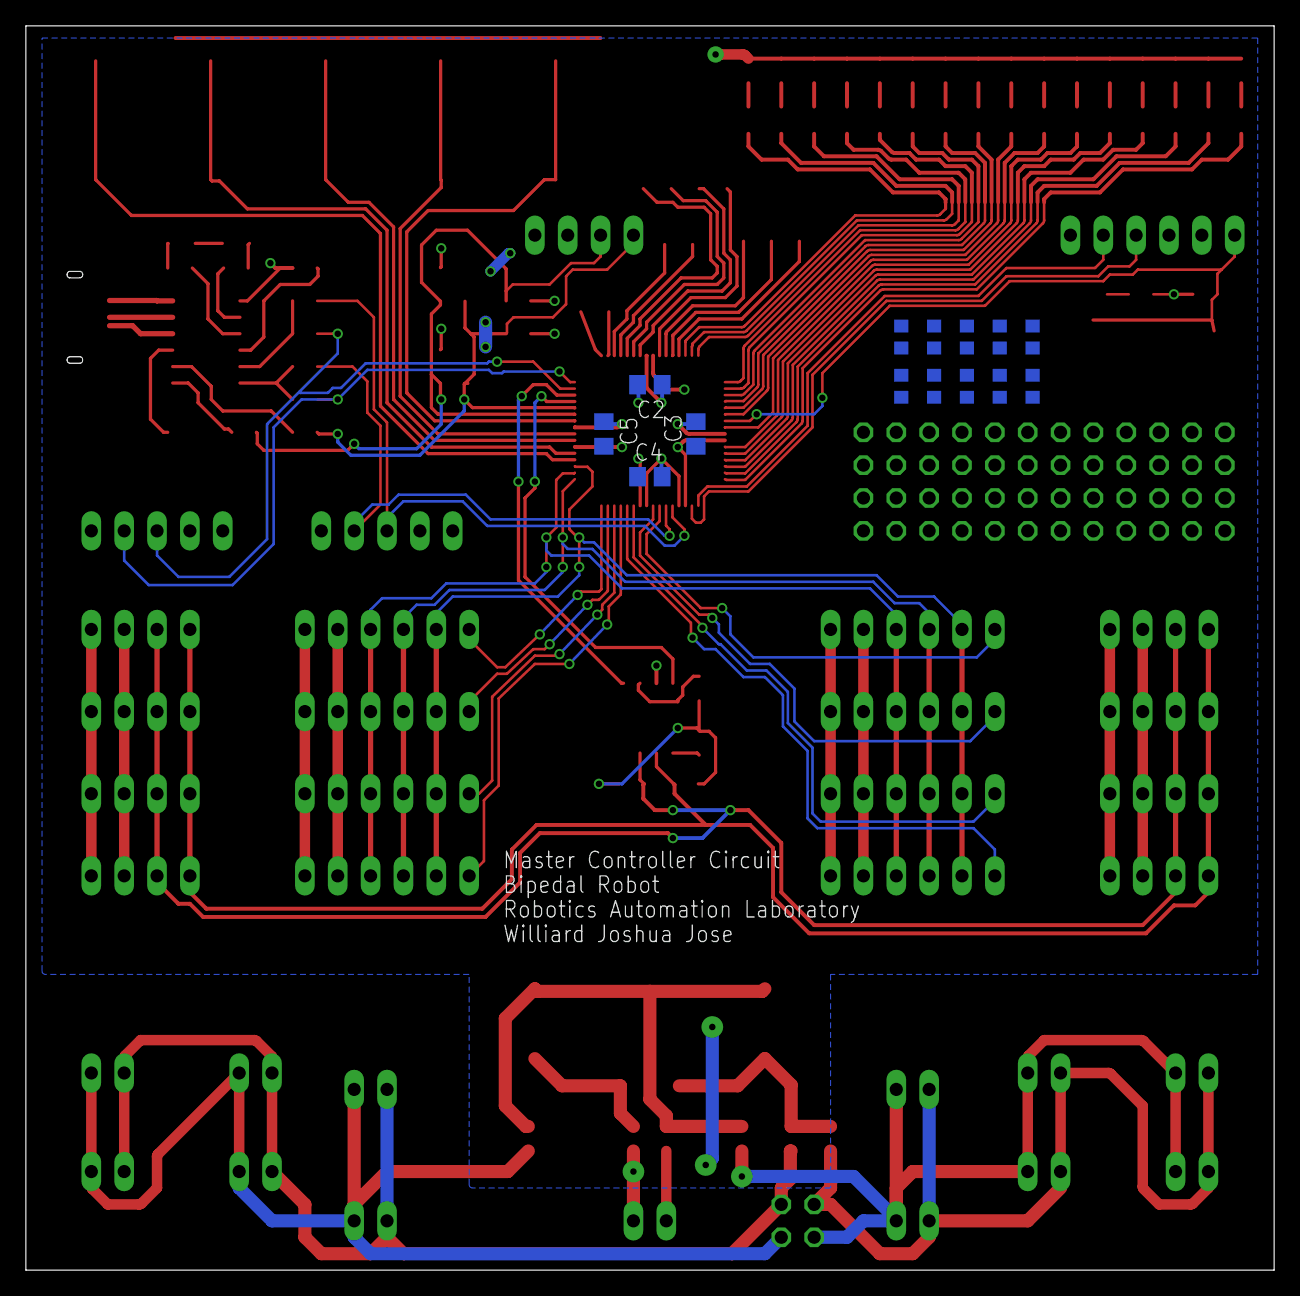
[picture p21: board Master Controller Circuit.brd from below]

Board: 2 copper layers, 96.5 x 96.2 mm, 145 parts (14 on the bottom side), 97 nets.

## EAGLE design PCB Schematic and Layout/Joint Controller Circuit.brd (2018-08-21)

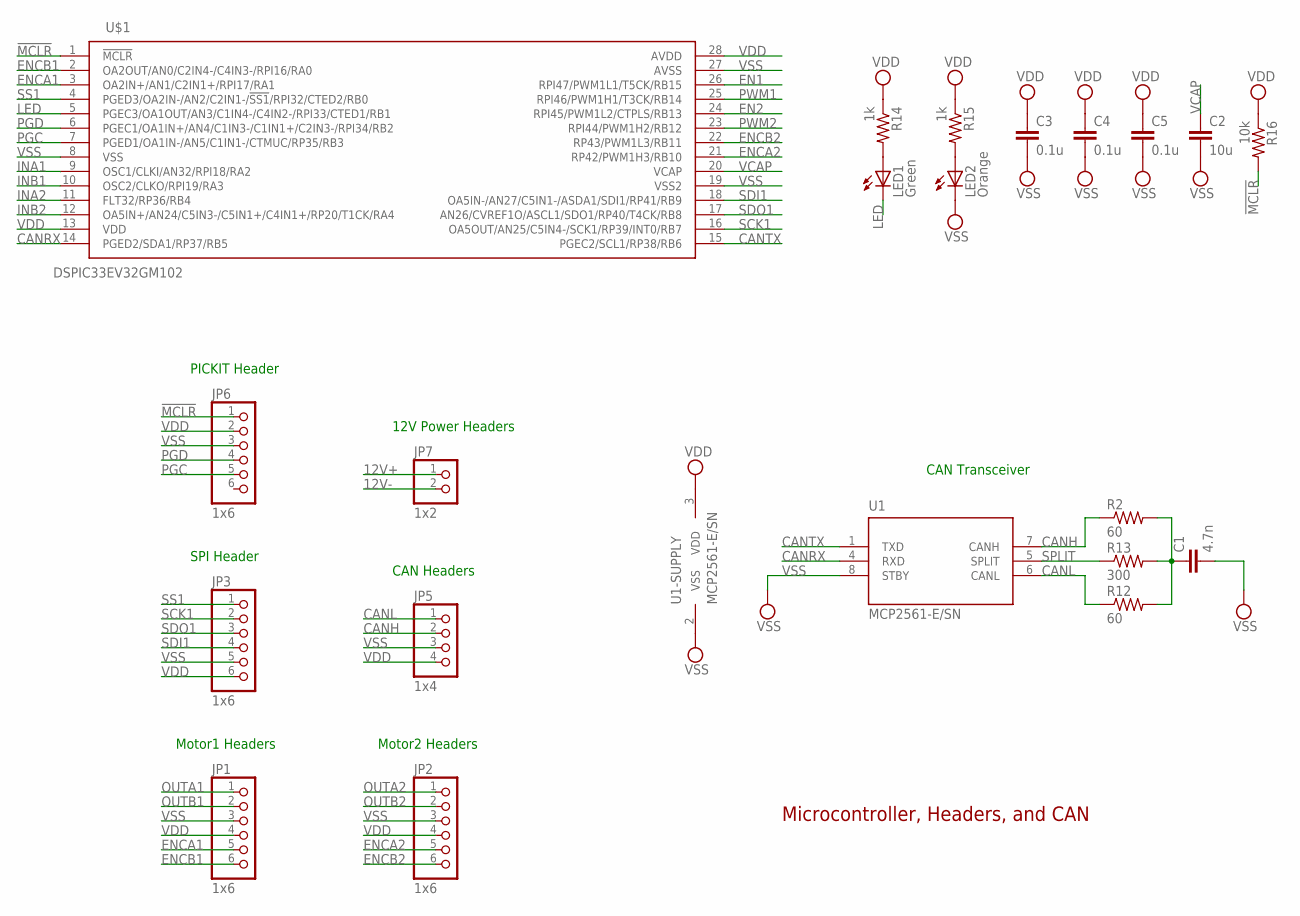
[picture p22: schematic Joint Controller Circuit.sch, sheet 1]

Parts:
C1: 4.7n; C0805
C2: 10u; C0805
C3, C4, C5: 0.1u; C0805
JP1, JP2, JP3, JP6: 1x6; 1X06
JP5: 1x4; 1X04
JP7: 1x2; 1X02
LED1: Green; CHIP-LED0805
LED2: Orange; CHIP-LED0805
R2, R12: 60; R0805
R13: 300; R0805
R14, R15: 1k; R0805
R16: 10k; R0805
U1: MCP2561-E/SN; SOIC-8
U$1: DSPIC33EV32GM102; SOIC28

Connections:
12V+: JP7.1; also elsewhere on the board
12V-: JP7.2; also elsewhere on the board
!MCLR: JP6.1, R16.2, U$1.1 (!MCLR)
CANH: JP5.2, R2.1, U1.7 (CANH)
CANL: JP5.1, R12.1, U1.6 (CANL)
CANRX: U1.4 (RXD), U$1.14 (PGED2/SDA1/RP37/RB5)
CANTX: U1.1 (TXD), U$1.15 (PGEC2/SCL1/RP38/RB6)
EN1: U$1.26 (RPI47/PWM1L1/T5CK/RB15); also elsewhere on the board
EN2: U$1.24 (RPI45/PWM1L2/CTPLS/RB13); also elsewhere on the board
ENCA1: JP1.5, U$1.3 (OA2IN+/AN1/C2IN1+/RPI17/RA1)
ENCA2: JP2.5, U$1.21 (RP42/PWM1H3/RB10)
ENCB1: JP1.6, U$1.2 (OA2OUT/AN0/C2IN4-/C4IN3-/RPI16/RA0)
ENCB2: JP2.6, U$1.22 (RP43/PWM1L3/RB11)
INA1: U$1.9 (OSC1/CLKI/AN32/RPI18/RA2); also elsewhere on the board
INA2: U$1.11 (FLT32/RP36/RB4); also elsewhere on the board
INB1: U$1.10 (OSC2/CLKO/RPI19/RA3); also elsewhere on the board
INB2: U$1.12 (OA5IN+/AN24/C5IN3-/C5IN1+/C4IN1+/RP20/T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); also elsewhere on the board
LED: LED1.C, U$1.5 (PGEC3/OA1OUT/AN3/C1IN4-/C4IN2-/RPI33/CT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)
unnamed: C1.1, R2.2, R12.2, R13.2
unnamed: LED1.A, R14.2
unnamed: LED2.A, R15.2
OUTA1: JP1.1; also elsewhere on the board
OUTA2: JP2.1; also elsewhere on the board
OUTB1: JP1.2; also elsewhere on the board
OUTB2: JP2.2; also elsewhere on the board
PGC: JP6.5, U$1.7 (PGED1/OA1IN-/AN5/C1IN1-/CTMUC/RP35/RB3)
PGD: JP6.4, U$1.6 (PGEC1/OA1IN+/AN4/C1IN3-/C1IN1+/C2IN3-/R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)
PWM1: U$1.25 (RPI46/PWM1H1/T3CK/RB14); also elsewhere on the board
PWM2: U$1.23 (RPI44/PWM1H2/RB12); also elsewhere on the board
SCK1: JP3.2, U$1.16 (OA5OUT/AN25/C5IN4-/SCK1/RP39/INT0/RB7)
SDI1: JP3.4, U$1.18 (OA5IN-/AN27/C5IN1-/ASDA1/SDI1/RP41/RB9)
SDO1: JP3.3, U$1.17 (AN26/CVREF1O/ASCL1/SDO1/RP40/T4CK/RB8)
SPLIT: R13.1, U1.5 (SPLIT)
SS1: JP3.1, U$1.4 (PGED3/OA2IN-/AN2/C2IN1-/!SS1!/RPI32/CTE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)
VCAP: C2.1, U$1.20 (VCAP)
VDD: C3.1, C4.1, C5.1, JP1.4, JP2.4, JP3.6, JP5.4, JP6.2, R14.1, R15.1, R16.1, U1.3 (VDD), U$1.13 (VDD), U$1.28 (AVDD); also elsewhere on the board
VSS: C1.2, C2.2, C3.2, C4.2, C5.2, JP1.3, JP2.3, JP3.5, JP5.3, JP6.3, LED2.C, U1.2 (VSS), U1.8 (STBY), U$1.8 (VSS), U$1.19 (VSS2), U$1.27 (AVSS); also elsewhere on the board

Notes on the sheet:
SPI Header
PICKIT Header
CAN Headers
12V Power Headers
Motor1 Headers
Motor2 Headers
CAN Transceiver
Microcontroller, Headers, and CAN

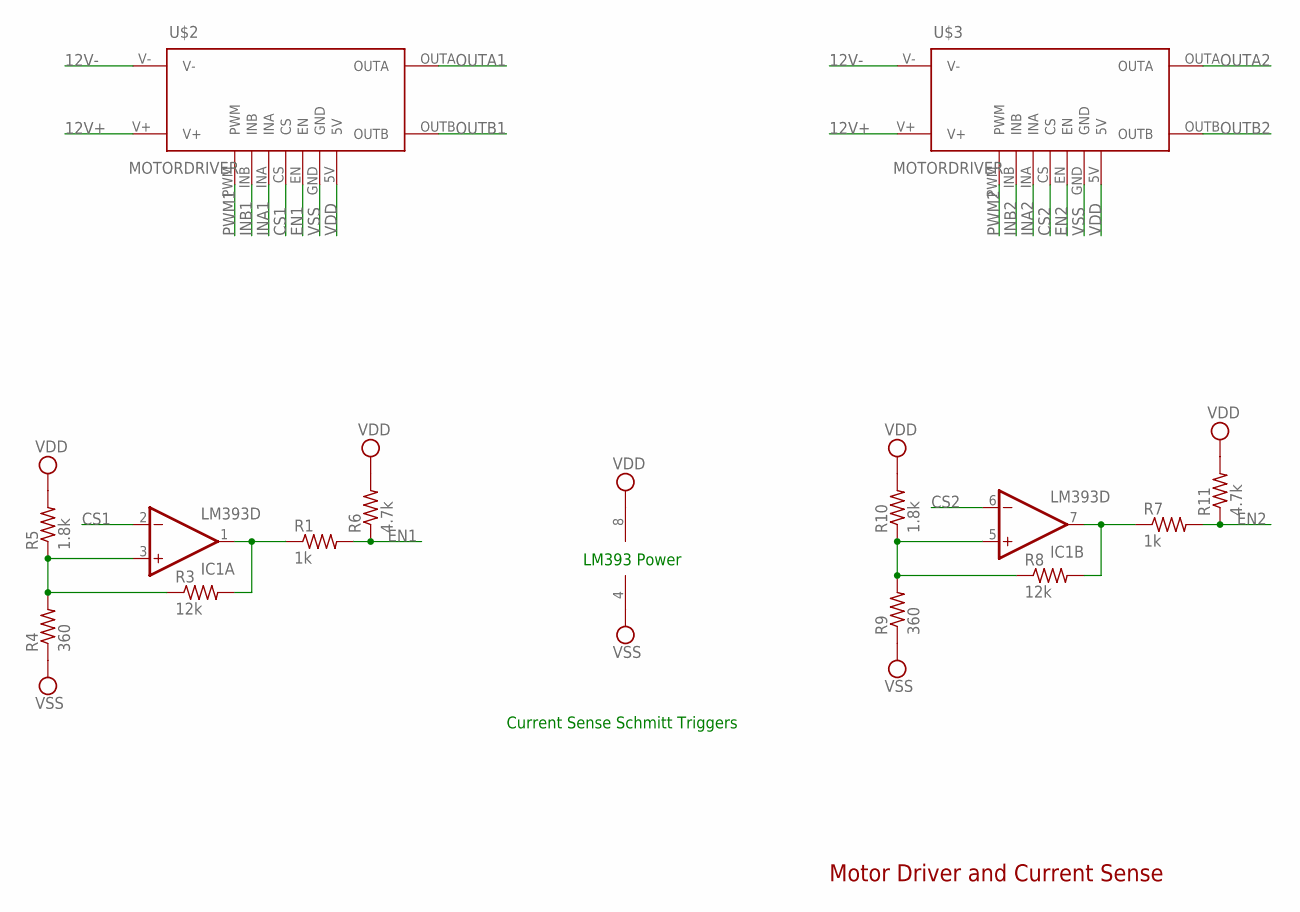
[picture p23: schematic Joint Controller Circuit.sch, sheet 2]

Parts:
IC1: LM393D; SO08
R1, R7: 1k; R0805
R3, R8: 12k; R0805
R4, R9: 360; R0805
R5, R10: 1.8k; R0805
R6, R11: 4.7k; R0805
U$2, U$3: MOTORDRIVER

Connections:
12V+: U$2.V+, U$3.V+; also elsewhere on the board
12V-: U$2.V-, U$3.V-; also elsewhere on the board
CS1: IC1.2 (-IN), U$2.CS
CS2: IC1.6 (-IN), U$3.CS
EN1: R1.2, R6.1, U$2.EN; also elsewhere on the board
EN2: R7.2, R11.1, U$3.EN; also elsewhere on the board
INA1: U$2.INA; also elsewhere on the board
INA2: U$3.INA; also elsewhere on the board
INB1: U$2.INB; also elsewhere on the board
INB2: U$3.INB; also elsewhere on the board
unnamed: IC1.7 (OUT), R7.1, R8.2
unnamed: IC1.5 (+IN), R8.1, R9.2, R10.1
unnamed: IC1.3 (+IN), R3.1, R4.2, R5.1
unnamed: IC1.1 (OUT), R1.1, R3.2
OUTA1: U$2.OUTA; also elsewhere on the board
OUTA2: U$3.OUTA; also elsewhere on the board
OUTB1: U$2.OUTB; also elsewhere on the board
OUTB2: U$3.OUTB; also elsewhere on the board
PWM1: U$2.PWM; also elsewhere on the board
PWM2: U$3.PWM; also elsewhere on the board
VDD: IC1.8 (V+), R5.2, R6.2, R10.2, R11.2, U$2.5V, U$3.5V; also elsewhere on the board
VSS: IC1.4 (V-), R4.1, R9.1, U$2.GND, U$3.GND; also elsewhere on the board

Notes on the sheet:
Current Sense Schmitt Triggers
LM393 Power
Motor Driver and Current Sense

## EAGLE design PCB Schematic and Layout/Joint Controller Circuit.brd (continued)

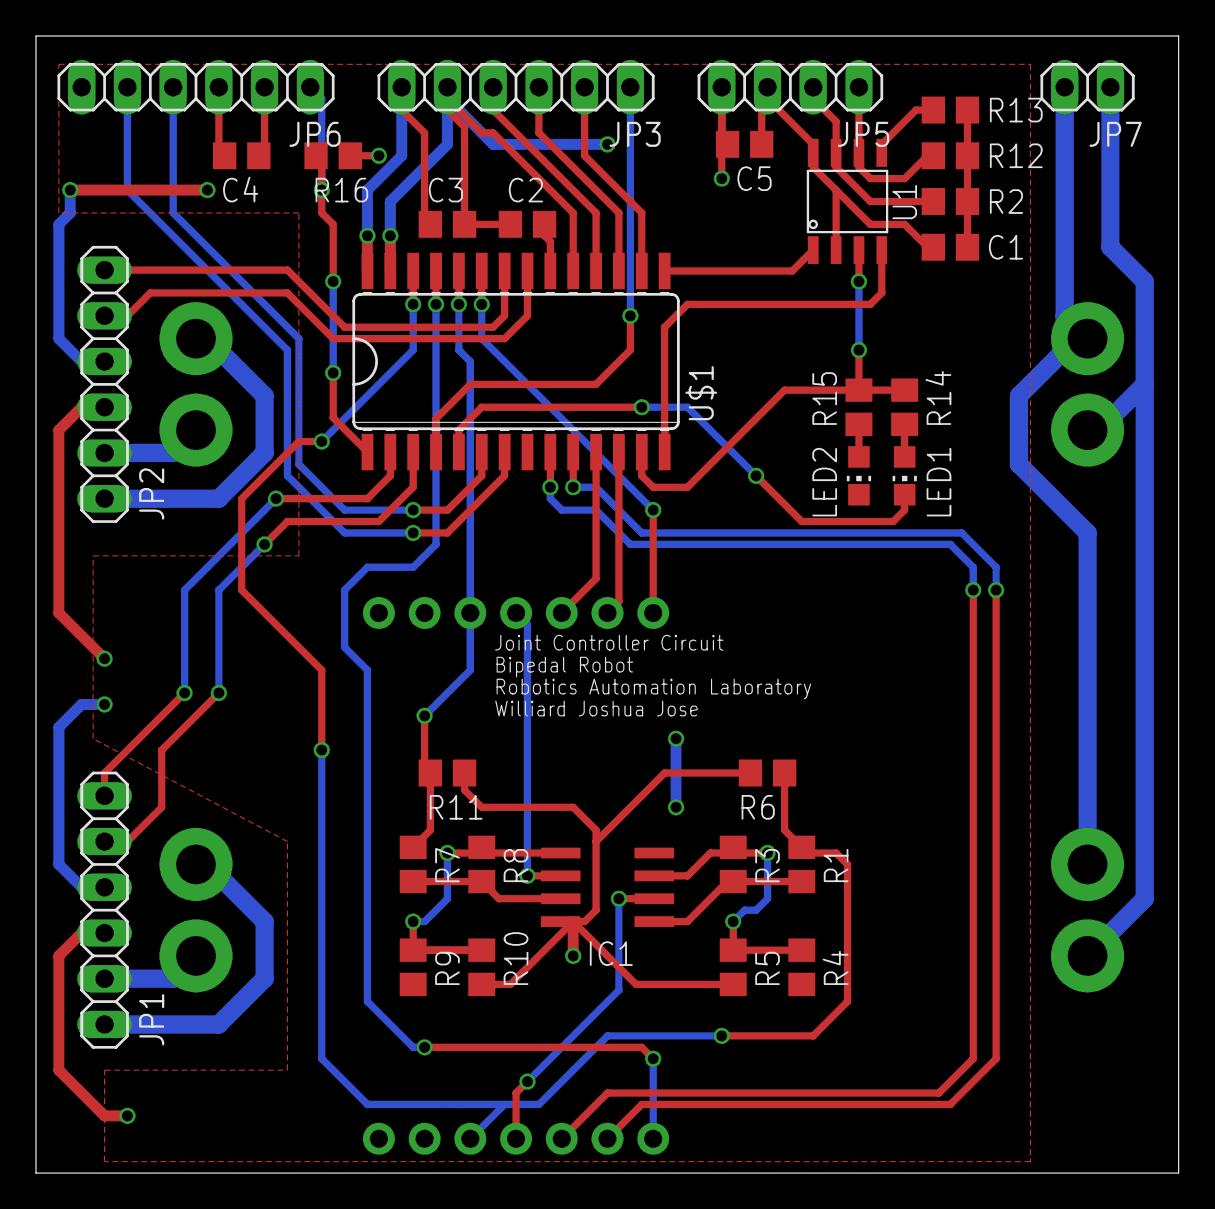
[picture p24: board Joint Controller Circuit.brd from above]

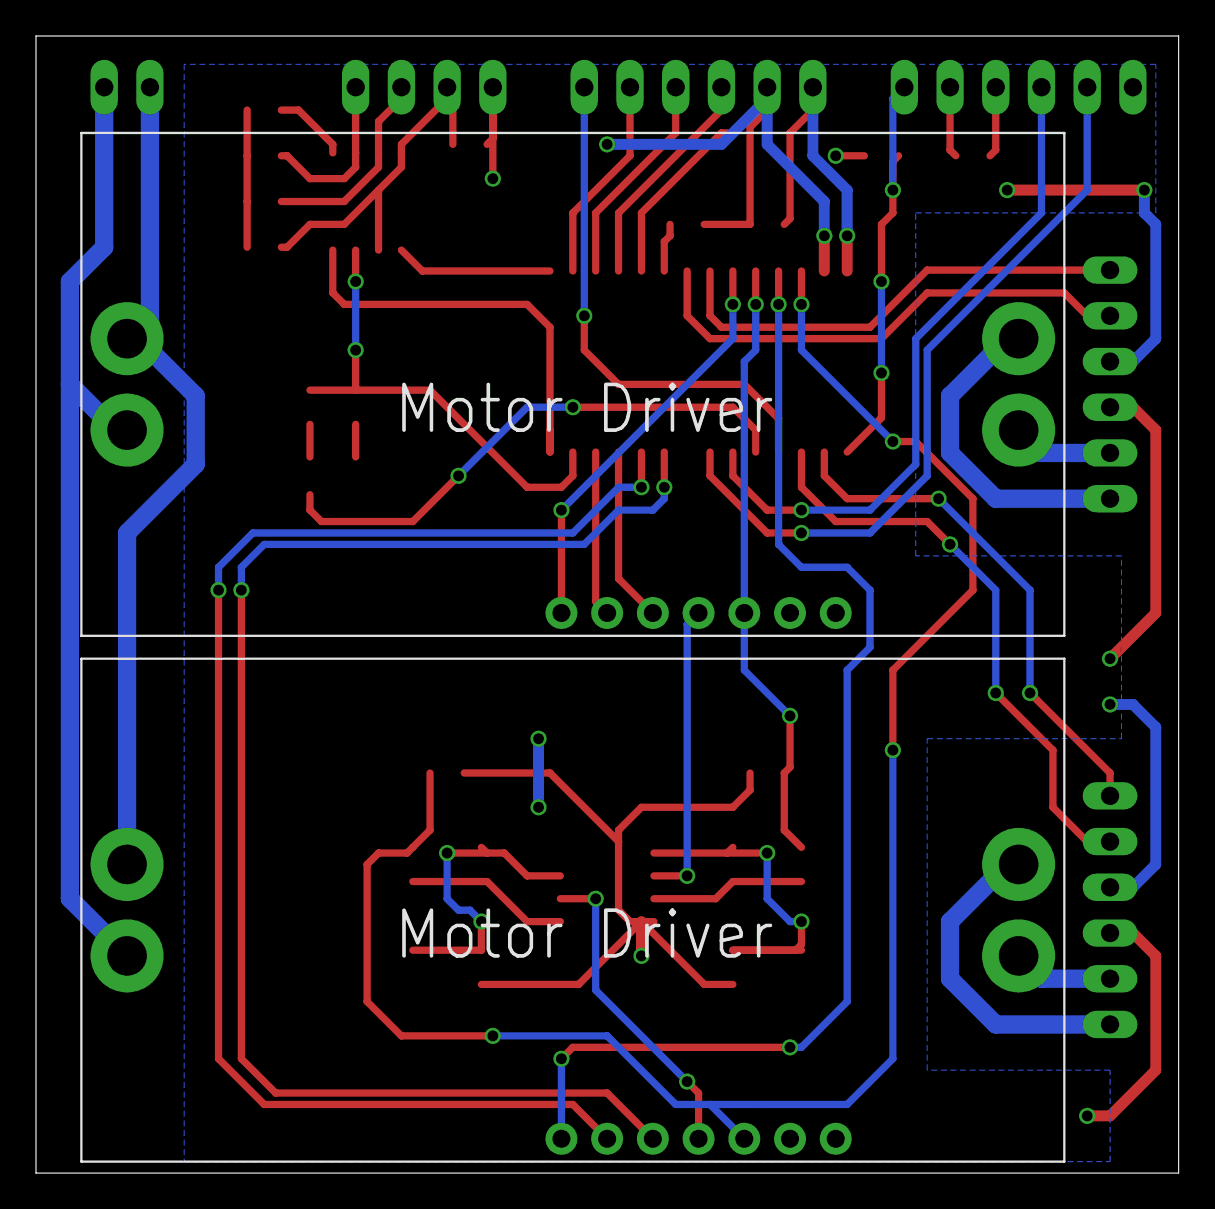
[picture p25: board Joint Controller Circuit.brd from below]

Board: 2 copper layers, 63.5 x 63.2 mm, 34 parts (2 on the bottom side), 43 nets.

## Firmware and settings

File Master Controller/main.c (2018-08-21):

#include "init.h"

/*********User editable variables*********/
//these constants are ordered by:
//	0 - right coronal ankle
//	1 - right sagittal ankle
//	2 - right sagittal knee
//	3 - right sagittal hip
//	4 - right coronal hip
//	5 - left coronal ankle
//	6 - left sagittal ankle
//	7 - left sagittal knee
//	8 - left sagittal hip
//	9 - left coronal hip
const int Kp[10] = {16000, 5000, 5000, 5000, 16000, 16000, 5000, 5000, 5000, 16000};
const int Ki[10] = {0, 0, 0, 0, 0, 0, 0, 0, 0, 0};
//const int Ki[10] = {5, 5, 5, 5, 5, 5, 5, 5, 5, 5};
//const int Ki[10] = {20, 20, 20, 20, 20, 20, 20, 20, 20, 20};
const int Kd[10] = {0, 0, 0, 0, 0, 0, 0, 0, 0, 0};
const int Kdiv[10] = {20, 20, 20, 20, 20, 20, 20, 20, 20, 20};
/*****End of user editable variables******/

void Init();
void Init_PID();
void sendPacket();

int ctr1, ctr2, requestctr;
char buffer[128];

volatile flags_t flags;
volatile packet_t packet;
volatile uint8_t state;
/*
	State 1: all joints powered down, idle mode
	State 2: joint positions are reset to initial
	State 3: joints are powered up to hold position
	State 4: motion is ongoing
	State 5: motion has been paused
	State 6: motion has just finished
*/
volatile int motion_ctr;

const uint8_t transform[2][6] = {
	{0, 2, 4, 5, 7, 9},
	{1, 2, 3, 6, 7, 8}
};

int main() {
	Init();
	while (1) {
//		UART1_process();
//		UART2_process();
		
		if (flags.can_receive1) {
			CAN_process(1);
			LED11 = ~LED11;
			flags.can_receive1 = 0;
		}
		if (flags.can_receive2) {
			CAN_process(2);
			LED12 = ~LED12;
			flags.can_receive2 = 0;
		}
		if (flags.can_receive3) {
			CAN_process(3);
			LED13 = ~LED13;
			flags.can_receive3 = 0;
		}
		if (flags.can_receive4) {
			CAN_process(4);
			LED14 = ~LED14;
			flags.can_receive4 = 0;
		}
		if (flags.can_receive5) {
			CAN_process(5);
			LED15 = ~LED15;
			flags.can_receive5 = 0;
		}
		if (flags.can_receive6) {
			CAN_process(6);
			LED16 = ~LED16;
			flags.can_receive6 = 0;
		}
		if (flags.can_receive == 0b111111) {
//			sprintf(buffer, "Setpnt: %5d %5d %5d %5d %5d %5d %5d %5d %5d %5d\n", motion[motion_ctr][0], motion[motion_ctr][1], 
//				motion[motion_ctr][2], motion[motion_ctr][3], motion[motion_ctr][4], motion[motion_ctr][5], 
//				motion[motion_ctr][6], motion[motion_ctr][7], motion[motion_ctr][8], motion[motion_ctr][9]);
//			UART1_print(buffer);
//			sprintf(buffer, "Actual: %5d %5d %5d %5d %5d %5d %5d %5d %5d %5d\n", CAN_buffer[0][0], CAN_buffer[0][1], 
//				CAN_buffer[1][1], CAN_buffer[2][1], CAN_buffer[2][0], CAN_buffer[3][0], 
//				CAN_buffer[3][1], CAN_buffer[4][1], CAN_buffer[5][1], CAN_buffer[5][0]);
//			UART1_print(buffer);
//			sprintf(buffer, "Torque: %5d %5d %5d %5d %5d %5d %5d %5d %5d %5d\n", CAN_buffer[0][2], CAN_buffer[0][3], 
//				CAN_buffer[1][3], CAN_buffer[2][3], CAN_buffer[2][2], CAN_buffer[3][2], 
//				CAN_buffer[3][3], CAN_buffer[4][3], CAN_buffer[5][3], CAN_buffer[5][2]);
//			UART1_print(buffer);
			
			flags.can_receive = 0;
		}
		
		if (flags.send_requeststate) {
			packet.Command = 0x0E;
			packet.Options1 = 0b11;
			packet.Options2 = 0b11;
			motion_ctr++;
			for (ctr1 = 0; ctr1 < 6; ctr1++) {
				packet.ID = ctr1 + 1;
				sendPacket(packet);
			}
			
			flags.send_requeststate = 0;
		}
		
		if (flags.timer10ms) {
			if (state == 4) {
//				if (requestctr == 0) {
//					packet.Options1 = 0b11;
//					packet.Options2 = 0b11;
//					requestctr = 0;
//				}
//				else {
					packet.Options1 = 0b01;
					packet.Options2 = 0b01;
//					requestctr++;
//				}
				motion_ctr++;
				for (ctr1 = 0; ctr1 < 6; ctr1++) {
					packet.ID = ctr1 + 1;
					
					packet.Command = 0x02;
					packet.Value1 = motion[motion_ctr][transform[0][ctr1]];
					packet.Value2 = motion[motion_ctr][transform[1][ctr1]];
					sendPacket(packet);
					
//					packet.Command = 0x0F;
//					packet.Value1 = basetorque[motion_ctr][transform[0][ctr1]];
//					packet.Value2 = basetorque[motion_ctr][transform[1][ctr1]];
//					sendPacket(packet);
				}
				if (motion_ctr >= motion_len - 1) {
					LED1 = LED2 = LED3 = LED4 = LED5 = LED6 = 1;
					LED6 = 0;
					state = 6;
				}
			}
			flags.timer10ms = 0;
		}
		if (flags.send_disable) {
			packet.Command = 0x06;
			packet.Options1 = 1;
			packet.Options2 = 1;
			packet.Value1 = 0;
			packet.Value2 = 0;
			for (ctr1 = 0; ctr1 < 6; ctr1++) {
				packet.ID = ctr1 + 1;
				sendPacket(packet);
			}
			flags.send_disable = 0;
		}
		if (flags.send_initializepos) {
			//set setpoint to 0
			packet.Options1 = 1;
			packet.Options2 = 1;
			packet.Value1 = 0;
			packet.Value2 = 0;
			for (ctr1 = 0; ctr1 < 6; ctr1++) {
				packet.ID = ctr1 + 1;
				packet.Command = 0x02;				//set setpoint to 0
				sendPacket(packet);
				packet.Command = 0x04;				//set current position to 0
				sendPacket(packet);
			}
			flags.send_initializepos = 0;
		}
		if (flags.send_enable) {
			packet.Command = 0x06;
			packet.Options1 = 1;
			packet.Options2 = 1;
			packet.Value1 = 1;
			packet.Value2 = 1;
			for (ctr1 = 0; ctr1 < 6; ctr1++) {
				packet.ID = ctr1 + 1;
				sendPacket(packet);
			}
			flags.send_enable = 0;
		}
		
		//Heartbeat
		if (flags.timer100ms) {
			LED10 = ~LED10;
//			UART2_write('g');
//			UART2_write('\n');
			flags.timer100ms = 0;
		}
	}
	return 0;
}

//idle state / emergency stop
void PB1release() {
	//send disable command to all joints
	flags.send_disable = 1;
	
	LED1 = LED2 = LED3 = LED4 = LED5 = LED6 = 1;
	LED1 = 0;
	state = 1;
}

//(re-)initialize joint positions
void PB2release() {
	if (state == 1) {				//ensure previous state is state 1
		//send set joints to 0
		flags.send_initializepos = 1;
		
		LED1 = LED2 = LED3 = LED4 = LED5 = LED6 = 1;
		LED2 = 0;
		state = 2;
	}
}

//power joints to hold position
void PB3release() {
	if (state == 2) {				//ensure previous state is state 2
		//send enable mode
		flags.send_enable = 1;
		
		LED1 = LED2 = LED3 = LED4 = LED5 = LED6 = 1;
		LED3 = 0;
		state = 3;
	}
}

//(re)start motion
void PB4release() {
	if (state == 3) {				//case when motion has just been started
		//start motion
		motion_ctr = -1;
		
		LED1 = LED2 = LED3 = LED4 = LED5 = LED6 = 1;
		LED4 = 0;
		state = 4;
	}
	else if (state == 5) {			//case when motion was paused
		//resume motion
		
		LED1 = LED2 = LED3 = LED4 = LED5 = LED6 = 1;
		LED4 = 0;
		state = 4;
	}
	//ensure previous state is state 3 or 5
	//if state 3: start motion
	//if state 5: resume motion
	//once done with entire motion, set state to state 6
}

//pause motion
void PB5release() {
//	if (state == 4) {				//case when motion is ongoing
//		//pause motion
//		
//		LED1 = LED2 = LED3 = LED4 = LED5 = LED6 = 1;
//		LED5 = 0;
//		state = 5;
//	}
	flags.send_requeststate = 1;
}

void Init() {
	Init_OSC();
	Init_Pins();
	Init_UART1();
	Init_UART2();
	Init_TMR4();
	Init_CN();
	Init_PushButton();
	Init_CAN();
	
	//heartbeat LED
	LED10 = 0;
	
	//status LEDs
	LED1 = 1;
	LED2 = 1;
	LED3 = 1;
	LED4 = 1;
	LED5 = 1;
	LED6 = 1;
	
	//joint LEDs
	LED11 = 1;
	LED12 = 1;
	LED13 = 1;
	LED14 = 1;
	LED15 = 1;
	LED16 = 1;
	
	//motion path LEDs
	LED7 = 0;			//motion 1
	LED8 = 1;			//motion 2
	LED9 = 1;			//motion 3
	
	//initialize state
	LED1 = 0;
	state = 1;
	
	//disable all flags
	flags.timer10ms = 0;
	flags.timer100ms = 0;
	flags.send_disable = 0;
	flags.send_enable = 0;
	flags.send_initializepos = 0;
	flags.send_powerjoints = 0;
	flags.send_requeststate = 0;
	flags.can_receive = 0;
	flags.can_receive1 = 0;
	flags.can_receive2 = 0;
	flags.can_receive3 = 0;
	flags.can_receive4 = 0;
	flags.can_receive5 = 0;
	flags.can_receive6 = 0;
	
	requestctr = 0;
	
	delay_ms(1000);
	//initialize PID constants
	Init_PID();
}

void Init_PID() {
	//Kp
	packet.Command = 0x08;
	packet.Options1 = 1;
	packet.Options2 = 1;
	for (ctr1 = 0; ctr1 < 6; ctr1++) {
		packet.ID = ctr1 + 1;
		packet.Value1 = Kp[transform[0][ctr1]];
		packet.Value2 = Kp[transform[1][ctr1]];
		sendPacket(packet);
	}
	
	//Ki
	packet.Command = 0x09;
	packet.Options1 = 1;
	packet.Options2 = 1;
	for (ctr1 = 0; ctr1 < 6; ctr1++) {
		packet.ID = ctr1 + 1;
		packet.Value1 = Ki[transform[0][ctr1]];
		packet.Value2 = Ki[transform[1][ctr1]];
		sendPacket(packet);
	}
	
	//Kd
	packet.Command = 0x0A;
	packet.Options1 = 1;
	packet.Options2 = 1;
	for (ctr1 = 0; ctr1 < 6; ctr1++) {
		packet.ID = ctr1 + 1;
		packet.Value1 = Kd[transform[0][ctr1]];
		packet.Value2 = Kd[transform[1][ctr1]];
		sendPacket(packet);
	}
	
	//Kdiv
	packet.Command = 0x0B;
	packet.Options1 = 1;
	packet.Options2 = 1;
	for (ctr1 = 0; ctr1 < 6; ctr1++) {
		packet.ID = ctr1 + 1;
		packet.Value1 = Kdiv[transform[0][ctr1]];
		packet.Value2 = Kdiv[transform[1][ctr1]];
		sendPacket(packet);
	}
}

void sendPacket(packet_t p) {
	int i;
	buffer[0] = 0x55;
	buffer[1] = p.ID;
	buffer[2] = p.Command;
	buffer[3] = p.Options1;
	buffer[4] = p.Options2;
	buffer[5] = (uint8_t)((p.Value1 >> 8) & 0xFF);
	buffer[6] = (uint8_t)(p.Value1 & 0xFF);
	buffer[7] = (uint8_t)((p.Value2 >> 8) & 0xFF);
	buffer[8] = (uint8_t)(p.Value2 & 0xFF);
	buffer[9] = 0;
	for (i = 1; i <= 8; i++) {
		unsigned int temp = buffer[i] & 0xFF;
		while (temp) {
			buffer[9] += temp & 1;
			temp >>= 1;
		}
	}
	buffer[10] = 0xAA;
	for (i = 0; i <= 10; i++) {
//		UART1_write(buffer[i]);
//		UART2_write(buffer[i]);
	}
	CAN_Transmit(SELF + p.ID, buffer + 1);
	delay_ms(1);
}

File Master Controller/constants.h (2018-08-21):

#ifndef CONSTANTS_H
#define	CONSTANTS_H

//controller ID
#define CONTROLLER_ID 0
#define SELF (0xf0 + CONTROLLER_ID)

//frequencies
#define FRC 7372800                 //FRC = 7.3728 MHz +-1%
#define FOSC (FRC/4*150/2)          //FOSC = 138.24 MHz
#define FCY (FOSC/2)                //FCY = 69.12 MHz
#define FBAUD(x) ((FCY/x)/4-1)      //FBAUD(115200) = 149

//led outputs
#define LED1 _LATB12
#define LED2 _LATB13
#define LED3 _LATA10
#define LED4 _LATA7
#define LED5 _LATB14
#define LED6 _LATB15
#define LED7 _LATG6
#define LED8 _LATG7
#define LED9 _LATG8
#define LED10 _LATG9
#define LED11 _LATA12
#define LED12 _LATA11
#define LED13 _LATA0
#define LED14 _LATA1
#define LED15 _LATB0
#define LED16 _LATB1

//pushbuttons
#define PB1 _RC4
#define PB2 _RC5
#define PB3 _RC12
#define PB4 _RC15
#define PB5 _RD8

#endif

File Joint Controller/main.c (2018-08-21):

#include "init.h"

#define ACCURACY 10

volatile flags_t flags;
volatile packet_t packet;

int ctr1, ctr2;
char buffer[128];

void sendState(char);

int main() {
	flags.timer10ms = 0;
	flags.timer200ms = 0;
	flags.packetrx = 0;
	flags.can_receive = 0;
	
	Init_OSC();
	Init_Pins();
	Init_Encoder();
	Init_CN();
	Init_PWM();
	Init_TMR4();
//	Init_UART();
	Init_CAN();
	
	Init_Control();
	Init_PWMInterrupt();
	
	
	
	LED = 0;
	int value1, value2;
	while (1) {
		//Command processing
//		UART_process();
		
//		if (flags.can_receive) {
//			delay_ms(50);
//			LED = ~LED;
//			flags.can_receive = 0;
//		}
//		continue;
		
		if (flags.packetrx || flags.can_receive) {
			value1 = (int)packet.Value1;
			value2 = (int)packet.Value2;
			switch (packet.Command) {
				//Reset
				case 0x01:
					asm ("RESET");
					break;

				//Set angle setpoint
				case 0x02:
					if (packet.Options1 & 1) {
						if (value1 < minsetpoint1)
							setpoint1 = minsetpoint1;
						else if (value1 > maxsetpoint1)
							setpoint1 = maxsetpoint1;
						else
							setpoint1 = value1;
					}
					if (packet.Options2 & 1) {
						if (value2 < minsetpoint2)
							setpoint2 = minsetpoint2;
						else if (value2 > maxsetpoint2)
							setpoint2 = maxsetpoint2;
						else
							setpoint2 = value2;
					}
					if ((packet.Options1 & (1 << 1)) || (packet.Options2 & (1 << 1))) {
						sendState(0);
					}
					break;

				//Increment angle setpoint
				case 0x03:
					if (packet.Options1 & 1) {
						if (setpoint1 + value1 < minsetpoint1)
							setpoint1 = minsetpoint1;
						else if (setpoint1 + value1 > maxsetpoint1)
							setpoint1 = maxsetpoint1;
						else
							setpoint1 += value1;
					}
					if (packet.Options2 & 1) {
						if (setpoint2 + value2 < minsetpoint2)
							setpoint2 = minsetpoint2;
						else if (setpoint2 + value2 > maxsetpoint2)
							setpoint2 = maxsetpoint2;
						else
							setpoint2 += value2;
					}
					break;

				//Set current position
				case 0x04:
					if (packet.Options1 & 1)
						pos1 = value1;
					if (packet.Options2 & 1)
						pos2 = value2;
					break;

				//Set angle setpoint to current position
				case 0x05:
					if (packet.Options1 & 1) {
						setpoint1 = pos1;
						if (setpoint1 < minsetpoint1)
							minsetpoint1 = setpoint1;
						else if (setpoint1 > maxsetpoint1)
							maxsetpoint1 = setpoint1;
					}
					if (packet.Options2 & 1) {
						setpoint2 = pos2;
						if (setpoint2 < minsetpoint2)
							minsetpoint2 = setpoint2;
						else if (setpoint2 > maxsetpoint2)
							maxsetpoint2 = setpoint2;
					}
					break;

				//Turn on/off motor control loop
				case 0x06:
					if (packet.Options1 & 1) {
						if (value1 & 1)
							EN1 = 1;
						else
							EN1 = 0;
					}
					if (packet.Options2 & 1) {
						if (value2 & 1)
							EN2 = 1;
						else
							EN2 = 0;
					}
					break;

				//Set maximum PWM duty cycle
				case 0x07:
					if (packet.Options1 & 1) {
						if (value1 <= PTPER)
							maxPWM1 = value1;
						else
							maxPWM1 = PTPER;
					}
					if (packet.Options2 & 1) {
						if (value2 <= PTPER)
							maxPWM2 = value2;
						else
							maxPWM2 = PTPER;
					}
					break;

				//Set Kp constant
				case 0x08:
					if (packet.Options1 & 1)
						Kp1 = value1;
					if (packet.Options2 & 1)
						Kp2 = value2;
					break;

				//Set Ki constant
				case 0x09:
					if (packet.Options1 & 1)
						Ki1 = value1;
					if (packet.Options2 & 1)
						Ki2 = value2;
					break;

				//Set Kd constant
				case 0x0A:
					if (packet.Options1 & 1)
						Kd1 = value1;
					if (packet.Options2 & 1)
						Kd2 = value2;
					break;

				//Set Kdiv constant
				case 0x0B:
					if (packet.Options1 & 1)
						Kdiv1 = value1;
					if (packet.Options2 & 1)
						Kdiv2 = value2;
					break;

				//Set setpoint minimum
				case 0x0C:
					if (packet.Options1 & 1) {
						if (value1 >= -5760 && value1 <= 5760 && value1 <= maxsetpoint1)
							minsetpoint1 = value1;
						if (setpoint1 < minsetpoint1)
							setpoint1 = minsetpoint1;
					}
					if (packet.Options2 & 1)
						if (value2 >= -5760 && value2 <= 5760 && value2 <= maxsetpoint2)
							minsetpoint2 = value2;
						if (setpoint2 < minsetpoint2)
							setpoint2 = minsetpoint2;
					break;

				//Set setpoint maximum
				case 0x0D:
					if (packet.Options1 & 1) {
						if (value1 >= -5760 && value1 <= 5760 && value1 >= minsetpoint1)
							maxsetpoint1 = value1;
						if (setpoint1 > maxsetpoint1)
							setpoint1 = maxsetpoint1;
					}
					if (packet.Options2 & 1)
						if (value2 >= -5760 && value2 <= 5760 && value2 >= minsetpoint2)
							maxsetpoint2 = value2;
						if (setpoint2 > maxsetpoint2)
							setpoint2 = maxsetpoint2;
					break;
				case 0x0E:
					if ((packet.Options1 & (1 << 1)) || (packet.Options2 & (1 << 1))) {
						sendState(1);
					}
					break;
				case 0x0F:
					if (packet.Options1 & 1)
						basetorque1 = value1;
					if (packet.Options2 & 1)
						basetorque2 = value2;
					break;
			}
			flags.packetrx = 0;
			flags.can_receive = 0;
		}

		//Heartbeat
		if (flags.timer200ms) {
			if (EN1 || EN2)
				LED = 0;
			else
				LED = ~LED;
			
			flags.timer200ms = 0;
		}
		if (flags.timer1000ms) {
			
			flags.timer1000ms = 0;
		}
	}
	return 0;
}

void sendState(char real) {
	int msg[4];
	if (real) {
		msg[0] = (int)realpos1;
		msg[1] = (int)realpos2;
	}
	else {
		msg[0] = (int)pos1;
		msg[1] = (int)pos2;
	}

	msg[2] = (int)signal1;
	msg[3] = (int)signal2;

	CAN_Transmit(SID_0r + CONTROLLER_ID, msg);
}

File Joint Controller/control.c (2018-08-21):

#include "init.h"

long Kp1 = 5000;
long Kd1 = 1000;
long Ki1 = 1;

long Kp2 = 5000;
long Kd2 = 1000;
long Ki2 = 1;

long Kdiv1 = 100;
long Kdiv2 = 100;

long maxPWM1, maxPWM2;
long minsetpoint1 = -5760, maxsetpoint1 = 5760;
long minsetpoint2 = -5760, maxsetpoint2 = 5760;

volatile long basetorque1, basetorque2;
volatile long setpoint1, setpoint2;
volatile long error1, error2;
volatile long sumerror1, sumerror2;
volatile long prevpos1, prevpos2;
volatile long currpos1, currpos2;
volatile long signal1, signal2;

void Init_Control() {
	//brake motors
	INA1 = 0;
	INB1 = 0;
	INA2 = 0;
	INB2 = 0;
	
	//set PWM duty cycle to 0/10000
	PWM1 = 0;
	PWM2 = 0;
	
	//disable motors
	EN1 = 0;
	EN2 = 0;
	
	maxPWM1 = PTPER;
	maxPWM2 = PTPER;
	
	sumerror1 = 0;
	sumerror2 = 0;
	prevpos1 = 0;
	prevpos2 = 0;
	
	setpoint1 = 0;
	setpoint2 = 0;
	
	basetorque1 = 0;
	basetorque2 = 0;
	
	pos1 = 0;
	pos2 = 0;
}

void Control_loop() {
	if (EN1) {
		currpos1 = pos1;
		error1 = currpos1 - setpoint1;
		sumerror1 += error1;
		signal1 = error1 * Kp1 / Kdiv1  + sumerror1 * Ki1 / Kdiv1 + (currpos1 - prevpos1) * Kd1 / Kdiv1 + basetorque1;
		prevpos1 = currpos1;
		if (signal1 < 0) {
			signal1 = -signal1;
			if (signal1 > maxPWM1)
				signal1 = maxPWM1;
			INA1 = 0;
			INB1 = 1;
			PWM1 = signal1;
		}
		else {
			if (signal1 > maxPWM1)
				signal1 = maxPWM1;
			INA1 = 1;
			INB1 = 0;
			PWM1 = signal1;
		}
	}
	
	if (EN2) {
		currpos2 = pos2;
		error2 = pos2 - setpoint2;
		sumerror2 += error2;
		signal2 = error2 * Kp2 / Kdiv2  + sumerror2 * Ki2 / Kdiv2 + (currpos2 - prevpos2) * Kd2 / Kdiv2 + basetorque2;
		prevpos2 = currpos2;
		if (signal2 < 0) {
			signal2 = -signal2;
			if (signal2 > maxPWM2)
				signal2 = maxPWM2;
			INA2 = 0;
			INB2 = 1;
			PWM2 = signal2;
		}
		else {
			if (signal2 > maxPWM2)
				signal2 = maxPWM2;
			INA2 = 1;
			INB2 = 0;
			PWM2 = signal2;
		}
	}
}

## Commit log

2018-08-21 Added SolidWorks 3D model of biped
    [Ankle Bearing.SLDPRT, Ankle DShaft.SLDPRT, Ankle Left.SLDPRT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]
2018-08-21 Added Joint Controller MPLAB project files
2018-08-21 Added EAGLE files for the schematic and layout of the joint and master controllers
    [Joint Controller Circuit.brd, Joint Controller Circuit.sch, Master Controller Circuit.brd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]

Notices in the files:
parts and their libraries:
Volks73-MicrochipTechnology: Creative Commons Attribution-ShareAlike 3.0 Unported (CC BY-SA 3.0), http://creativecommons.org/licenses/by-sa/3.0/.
